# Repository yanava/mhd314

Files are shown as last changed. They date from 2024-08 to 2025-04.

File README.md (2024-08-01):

# Mahaudio MHD314 Audio DAC for the RaspberryPi

This is a hardware project for an open Hi-Fi DAC design for the RaspberryPi. MHD stands for Mahaudio Hi-Fi DAC and 314 is an obvious reference to the Pi. 

## Description

This is a project conducted through a series of YouTube live events, which can be accessed on the following playlist: https://www.youtube.com/watch?v=isWnR_Fm9iQ&list=PLo5SrSJMaUGJOzglfgmpuGIEasF4YtCA1&pp=iAQB - Portuguese language only for now. The purpose is educational, to show audio enthusiasts what is the necessary work to develop and integrate a product.

## Presentations

All presentations used on the live events are available under the Documentation folder. 

## License

This project is licensed under the BSD-3 License.

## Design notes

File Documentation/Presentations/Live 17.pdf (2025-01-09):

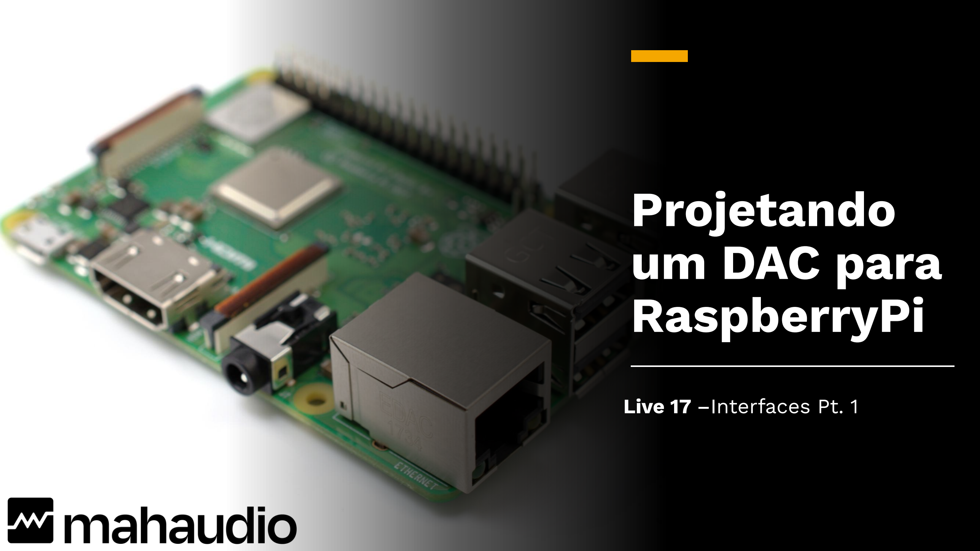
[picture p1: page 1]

# Projetando um DAC para RaspberryPi

## Live 17 –Interfaces Pt. 1

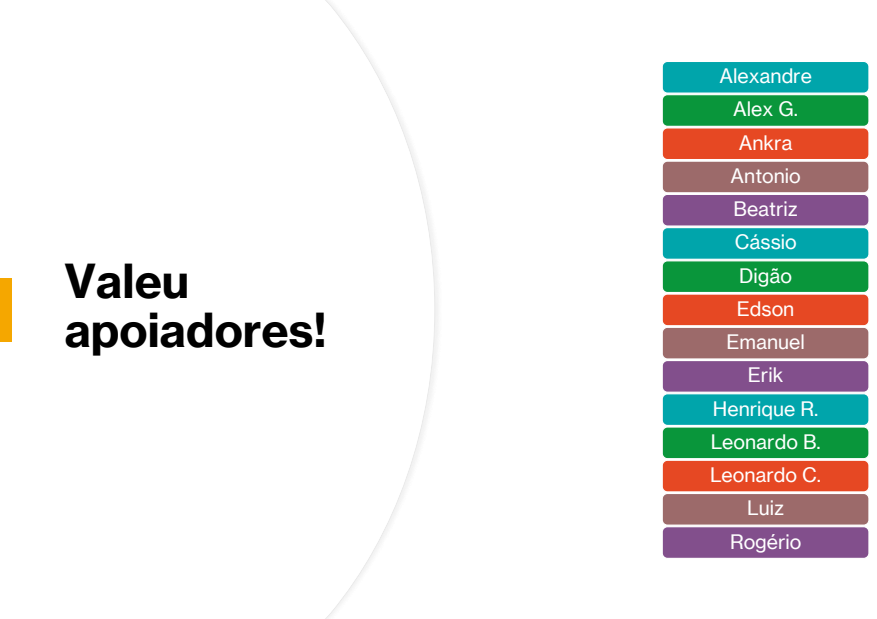
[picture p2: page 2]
Valeu apoiadores!; Alexandre; Alex G.; Ankra; Antonio; Beatriz; Cássio; Digão; Edson; Emanuel; Erik; Henrique R.; Leonardo B.; Leonardo C.; Luiz; Rogério

# Terminamos a fonte!

# Na última live

# Interfaces

## - Entrada – RaspberryPi

## - Saída – Conectores de Audio

## - Usuário – Controles e Indicadores

# Revendo nossa especificação

Item | Descrição | Requisito | Prioridade | Justificativa
1 | Tamanho | 65 x 56.5mm | Referência | Norma
2 | Entrada áudio | I2S – SCK, WS e SD | Obrigatório | Compatibilidade com RPi
3 | Saída SE - Conector | 3.5mm TRS | Obrigatório | Conectividade
4 | Saída DIFF - Conector | 4.4mm Pentaconn | Obrigatório | Conectividade
5 | Potência de Saída | 150mW RMS | Obrigatório | Fones target
6 | Entrada energia | 5V – 500mA 3.3V – 500mA | Referência | Compatibilidade com fontes de mercado p/ RPi

# Revendo nosso diagrama de blocos

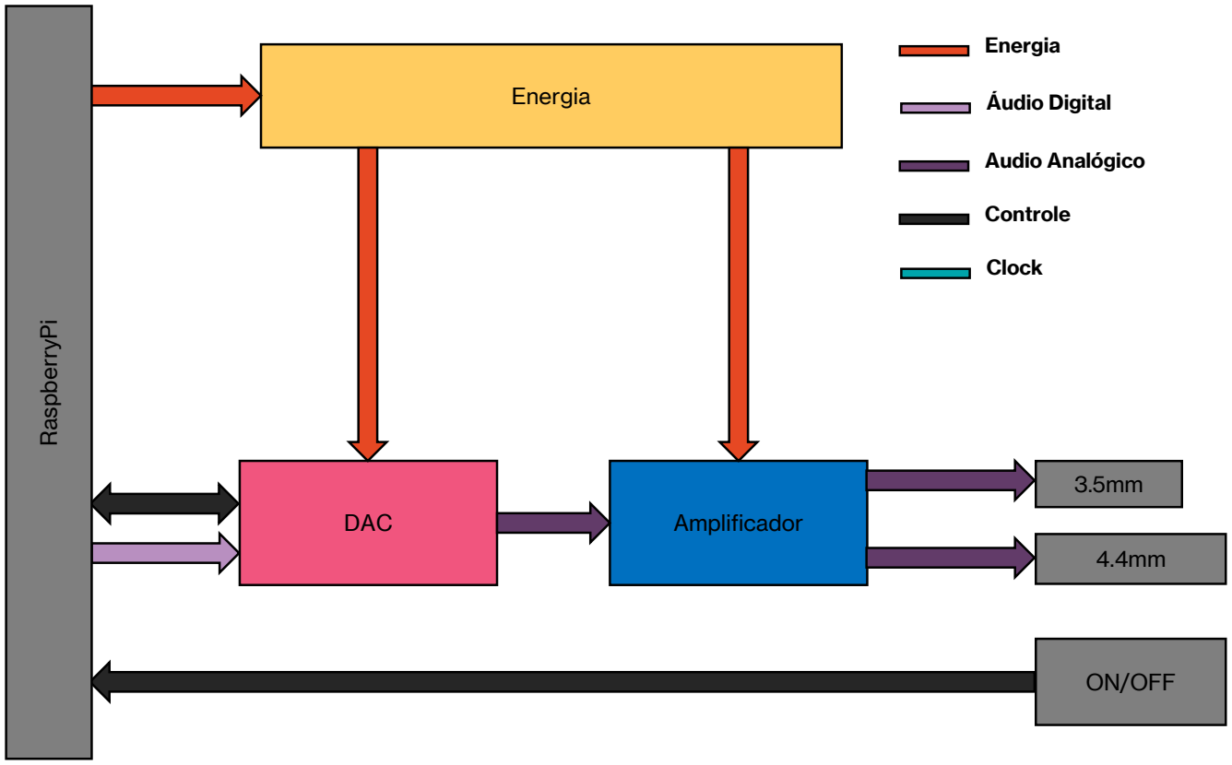
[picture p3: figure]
Energia; DAC; Amplificador; ON/OFF; RaspberryPi; Audio Analógico; Controle; Clock; Áudio Digital

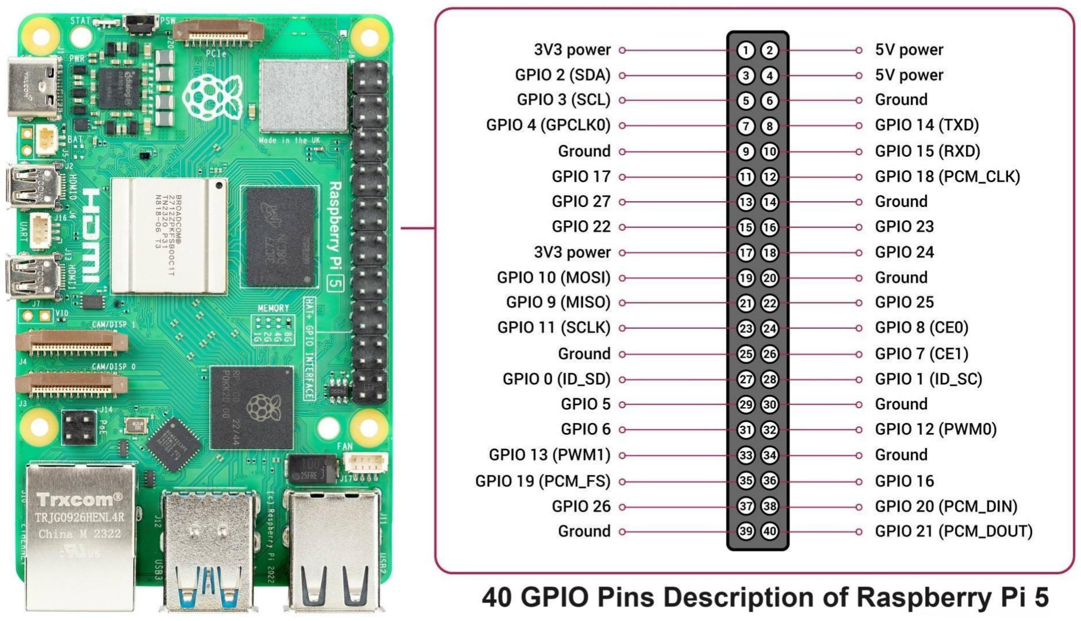
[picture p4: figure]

# Conector da RaspberryPi

# BCM Peripherals

## - Documento listando todos os periféricos do chip principal

## - Mostra distribuição dos periféricos em todos os pinos

## - Diferentes alocações são possíveis

## - Vamos fazer um tour do documento

# Pinos necessários

- Áudio – 3 Pinos
- 1 pino PCM_DATA
- 1 pino PCM_FS
- 1 pino PCM_CLK
- Controle – 8 Pinos
- 1 pino I2C_SCL
- 1 pino I2C_SDA
- 1 pino GPIO para Reset do ES9038Q2M
- 1 pino GPIO para Mute do OPA1622 Single Ended
- 1 pino GPIO para Mute do OPA1622 Diferencial
- 3 Pinos para LED
- Reconhecimento – 2 Pinos
- 1 pino ID_SD
- 1 pino ID_SC
- Alimentação – 10 Pinos
- 2 pinos de +5V
- 8 pinos GND (Terra)

# 23 de 40 Pinos

Alocando os pinos temos...

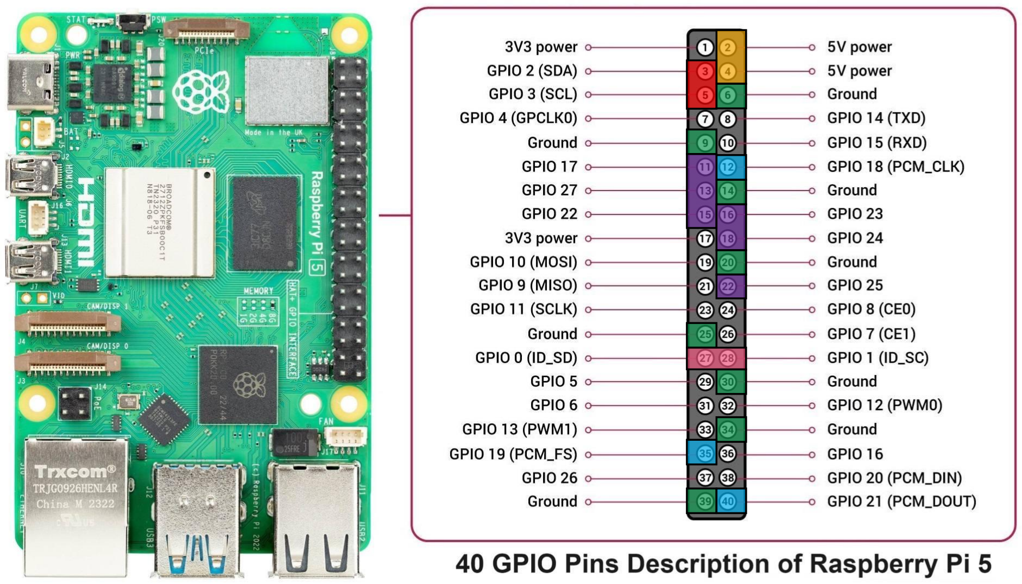
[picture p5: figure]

# Esquema de Identificação

## - Memória EEPROM na nossa placa

## - Identificação automática

## - Plug and play

## - Automaticamente carrega os drivers

## - Apenas 2 pinos

## - Documentação no Github da RPi

# Conectores de Áudio

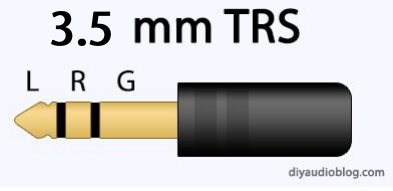
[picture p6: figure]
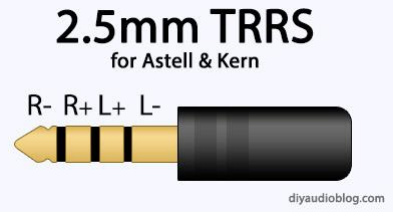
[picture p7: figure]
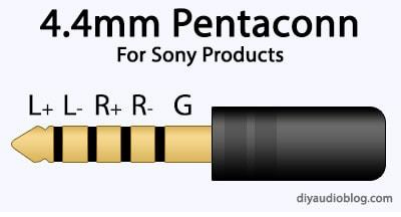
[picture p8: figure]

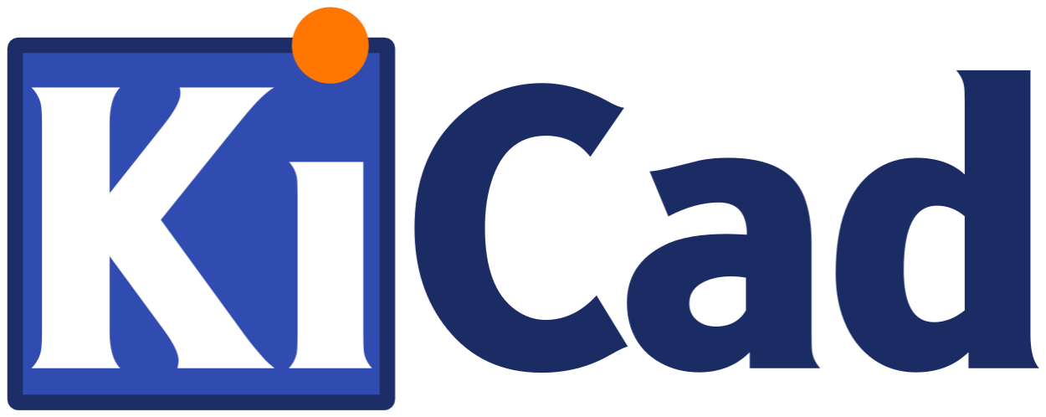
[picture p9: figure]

# Bora pro KiCad!

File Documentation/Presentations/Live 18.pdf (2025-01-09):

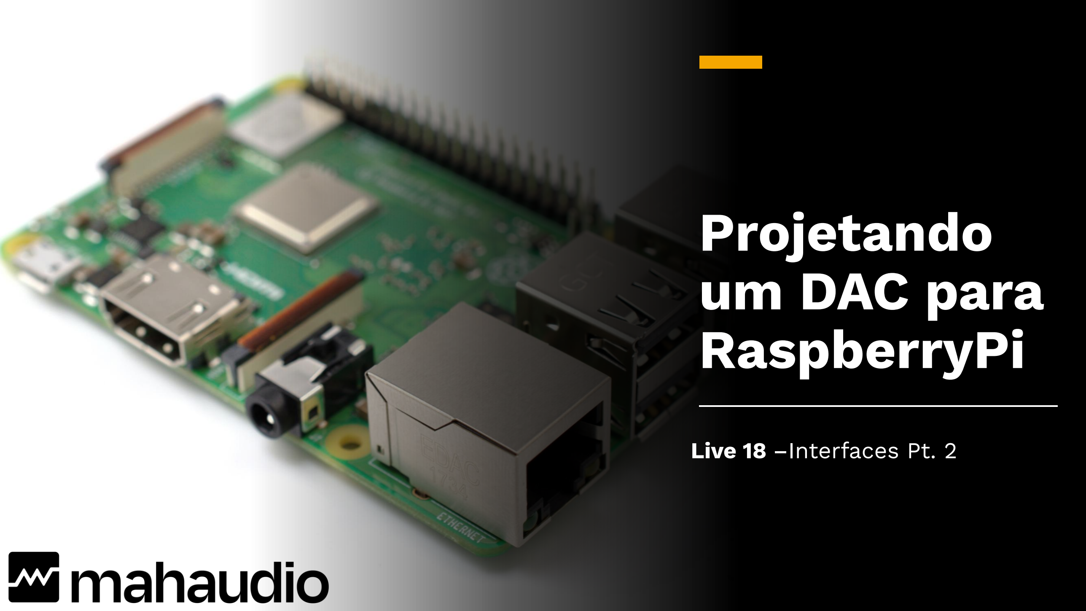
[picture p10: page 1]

# Projetando um DAC para RaspberryPi

### Live 18 –Interfaces Pt. 2

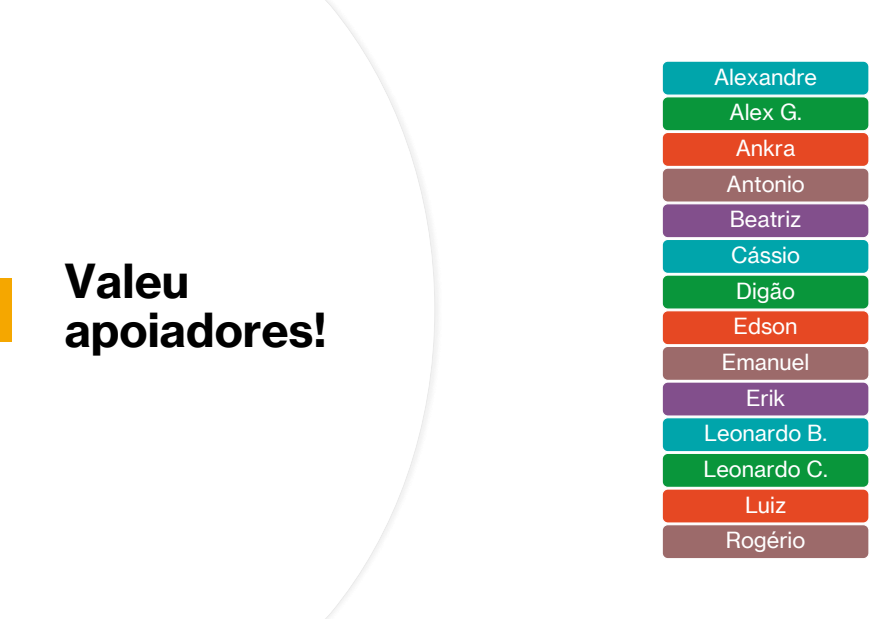
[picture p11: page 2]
Valeu apoiadores!; Alexandre; Alex G.; Ankra; Antonio; Beatriz; Cássio; Digão; Edson; Emanuel; Erik; Leonardo B.; Leonardo C.; Luiz; Rogério

# Na última live

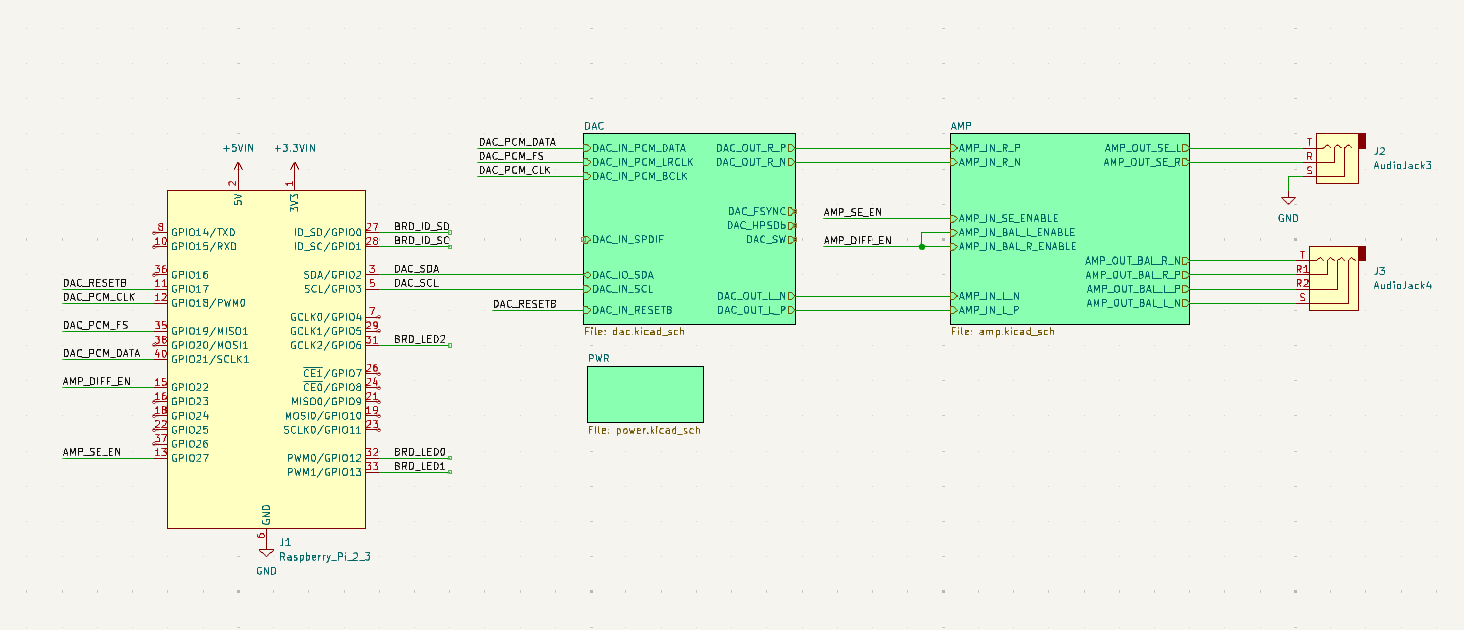
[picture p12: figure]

# Nesta live

### - Footprint dos conectores

### - LEDs

### - EEPROM

### - Testpoints


# Bora pro KiCad!

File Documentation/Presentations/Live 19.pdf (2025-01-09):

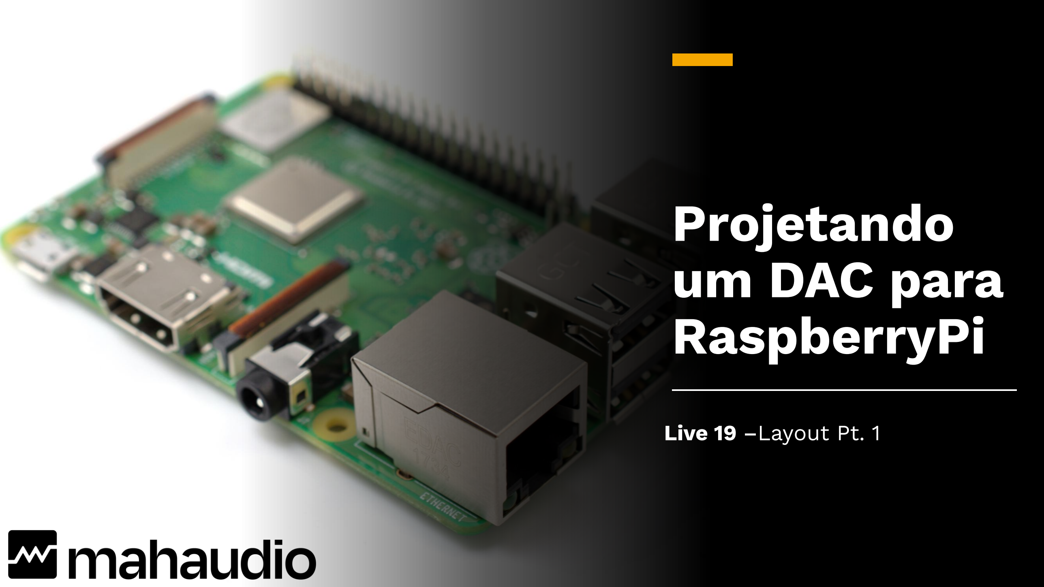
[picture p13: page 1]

# Projetando um DAC para RaspberryPi

### Live 19 –Layout Pt. 1

Valeu apoiadores!; Alexandre; Alex G.; Ankra; Antonio; Beatriz; Cássio; Digão; Edson; Emanuel; Erik; Leonardo B.; Leonardo C.; Luiz; Rogério

# Na última live

### - Fim do esquema elétrico!

# Nesta live

### - Tour do esquema

### - Passar tudo para a placa!


# Bora pro KiCad!

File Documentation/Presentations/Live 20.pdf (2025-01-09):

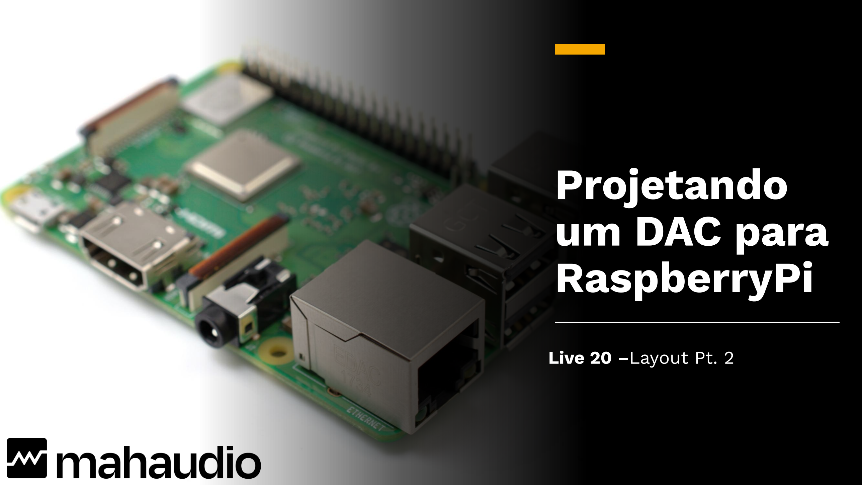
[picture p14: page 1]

# Projetando um DAC para RaspberryPi

### Live 20 –Layout Pt. 2

Valeu apoiadores!; Alexandre; Alex G.; Ankra; Antonio; Beatriz; Cássio; Digão; Edson; Emanuel; Erik; Leonardo B.; Leonardo C.; Luiz; Rogério

# Na última live

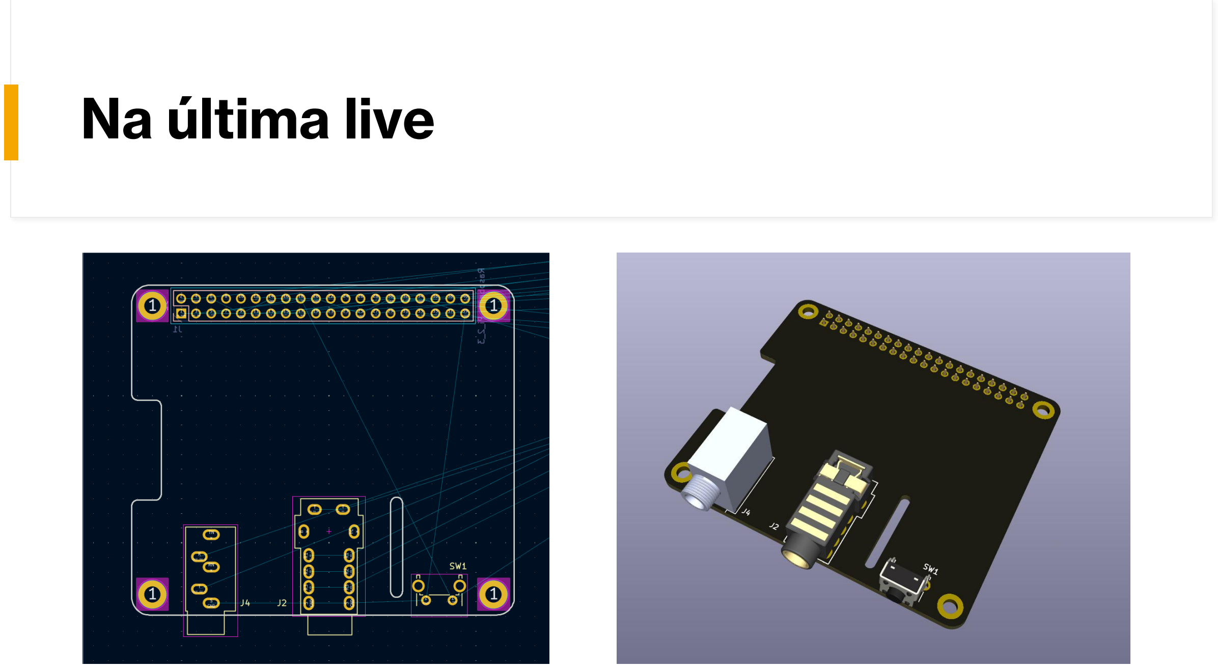
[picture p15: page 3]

# Nesta live - Placement

### - Conectores (OK!)

### - Fonte de alimentação

### - DAC

### - AMP


# Bora pro KiCad!

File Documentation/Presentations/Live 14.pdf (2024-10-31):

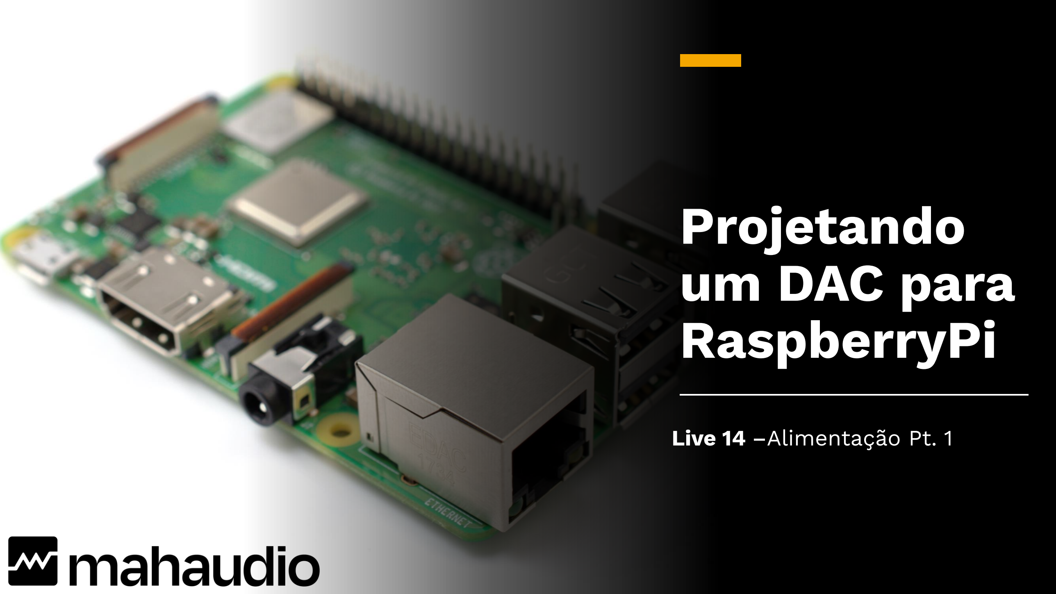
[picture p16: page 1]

# Projetando um DAC para RaspberryPi

Live 14 –Alimentação Pt. 1

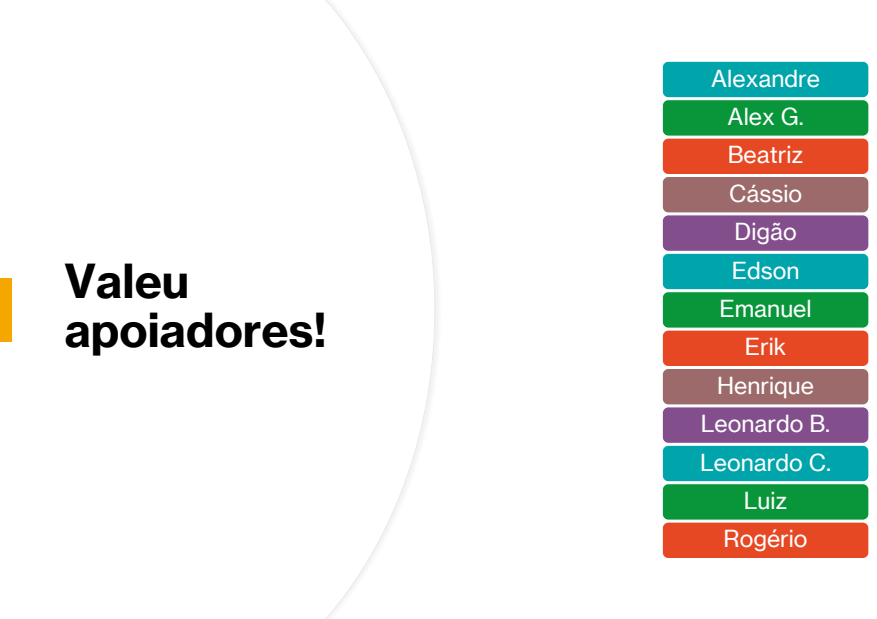
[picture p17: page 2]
Valeu apoiadores!; Alexandre; Alex G.; Beatriz; Cássio; Digão; Edson; Emanuel; Erik; Henrique; Leonardo B.; Leonardo C.; Luiz; Rogério

# Sorteios KZ ZS10 Pro 2 (Reloaded)

### - Aberto

- KZ ZS10 Pro 2 + Camiseta Amplificou Direito
- Regra: Comentário no LIVE de HOJE!
- Sorteio na próxima LIVE – a combinar
- Corte – (Data da live – 1) dia
- Todos apoiadores acima do nível Técnico já participam

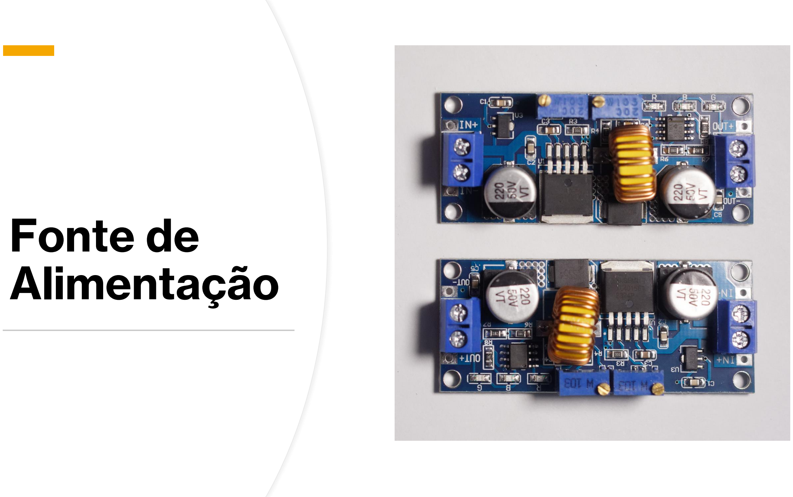
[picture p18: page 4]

# Fonte de Alimentação

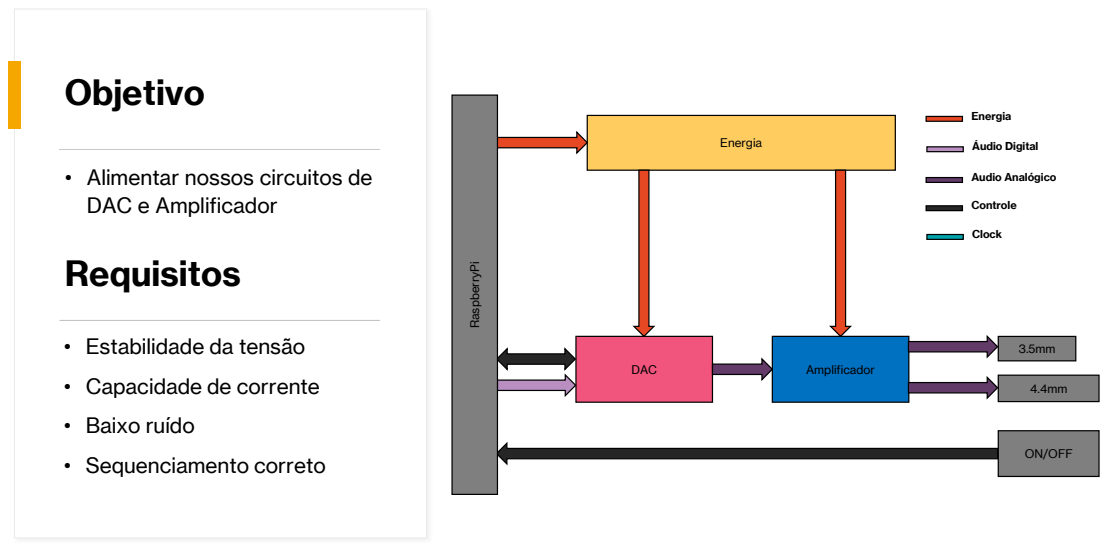
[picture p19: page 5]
DAC e Amplificador; Energia; DAC; Amplificador; ON/OFF; RaspberryPi; Audio Analógico; Controle; Clock; Áudio Digital; Requisitos

Objetivo • Alimentar nossos circuitos de

• Estabilidade da tensão • Capacidade de corrente • Baixo ruído • Sequenciamento correto

# Lembrando nossa spec

### - Tensões de entrada vindas da RaspberryPi (requisito)

Item | Descrição | Requisito | Prioridade | Justificativa
1 | Tamanho | 65 x 56.5mm | Referência | Norma
2 | Entrada áudio | I2S – SCK, WS e SD | Obrigatório | Compatibilidade com RPi
3 | Saída SE - Conector | 3.5mm TRS | Obrigatório | Conectividade
4 | Saída DIFF - Conector | 4.4mm Pentaconn | Obrigatório | Conectividade
5 | Potência de Saída | 150mW RMS | Obrigatório | Fones target
6 | Entrada energia | 5V – 500mA 3.3V – 500mA | Referência | Compatibilidade com fontes de mercado p/ RPi

# Reguladores de Tensão Lineares

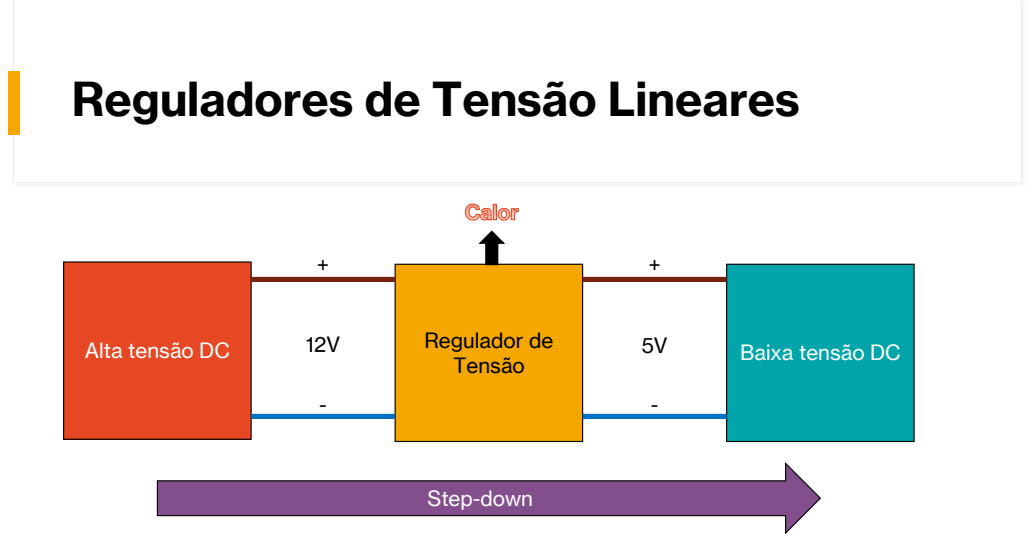
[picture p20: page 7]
Alta tensão DC; Baixa tensão DC Regulador de; Tensão; Step-down; Calor

# Reguladores Lineares

### - Vantagens

- Simples de projetar (+ poucos componentes)
- Baixo ruído
- Reação rápida a variações na carga

### - Desvantagens

- Eficiência menor (comparada a DC-DC)
- Apenas abaixam tensão
- Podem dissipar bastante calor

# Reguladores Chaveados (DC-DC)

Alta tensão DC | Baixa tensão DC Conversor
DC-DC

+

+

Step-down

Step-up

12V | 5V

# Reguladores DC-DC inversores (chaveados)

Alta tensão DC | Baixa tensão DC Conversor
DC-DC

+

+

Inverter

5V | -12V

# Reguladores Chaveados

### - Vantagens

- Alta eficiência
- Versatilidade
- Correntes de saída maiores

### - Desvantagens

- Mais complexos de projetar (+ componentes)
- Ruído de chaveamento
- Resposta a transiente

# Metodologia

### - Tomamos nota de todas as tensões que precisamos

### - Requisitos de corrente para cada tensão

### - Escolha de topologia

- Tensões exclusivamente analógicas → Reguladores lineares
- Tensões exclusivamente digitais → Reguladores chaveados
- Podemos usar reguladores chaveados para subir tensão e lineares para reduzir o ruído

### - Escolha dos componentes

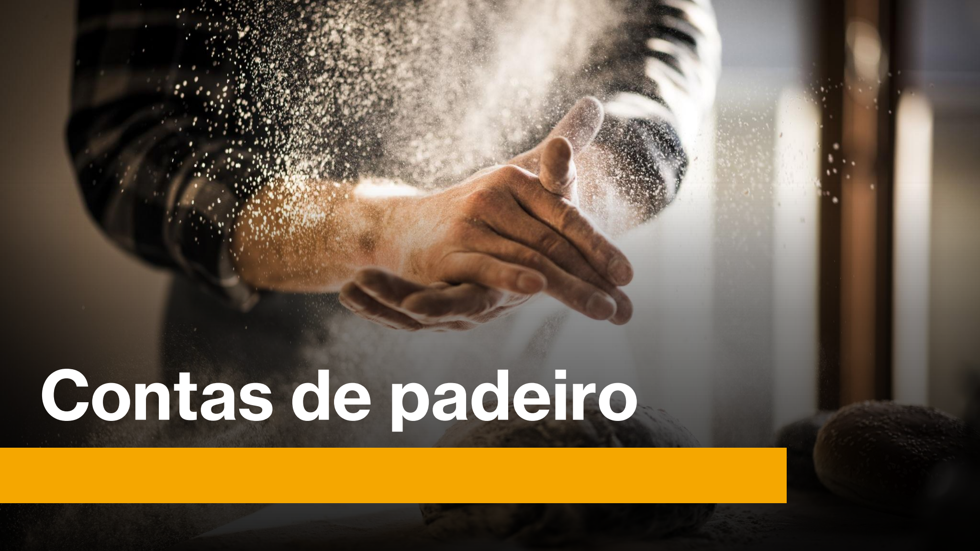
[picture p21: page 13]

# Contas de padeiro

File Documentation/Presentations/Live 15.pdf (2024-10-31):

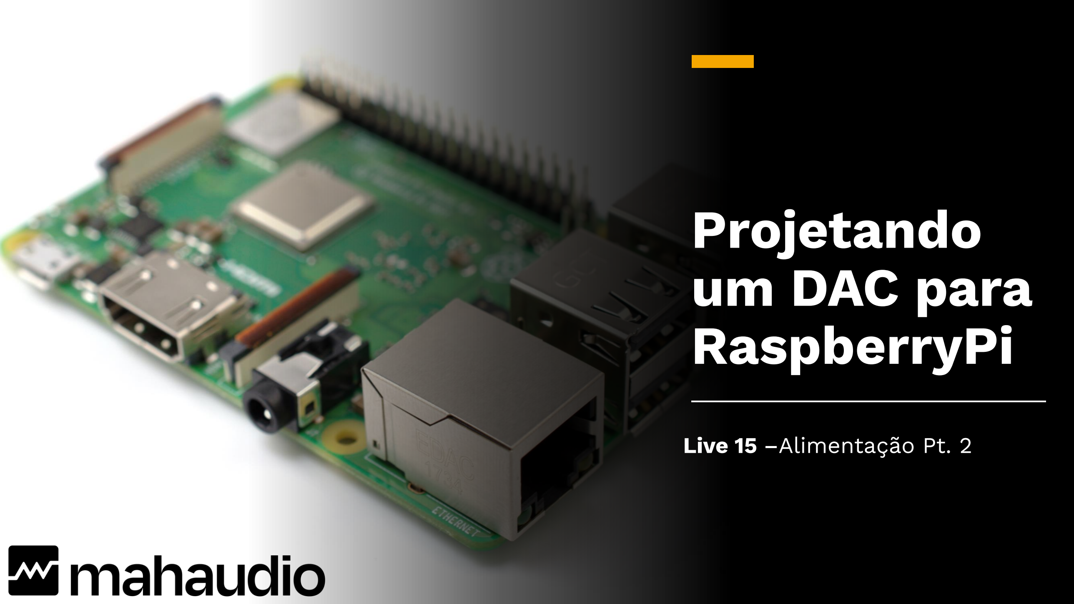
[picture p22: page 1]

# Projetando um DAC para RaspberryPi

## Live 15 –Alimentação Pt. 2

Valeu apoiadores!; Alexandre; Alex G.; Beatriz; Cássio; Digão; Edson; Emanuel; Erik; Henrique; Leonardo B.; Leonardo C.; Luiz; Rogério

# Sorteios KZ ZS10 Pro 2 (Reloaded)

## - Aberto

- KZ ZS10 Pro 2 + Camiseta Amplificou Direito
- Regra: Comentário no LIVE de HOJE!
- Sorteio na próxima LIVE – a combinar
- Corte – (Data da live – 1) dia
- Todos apoiadores acima do nível Técnico já participam

# Na última live

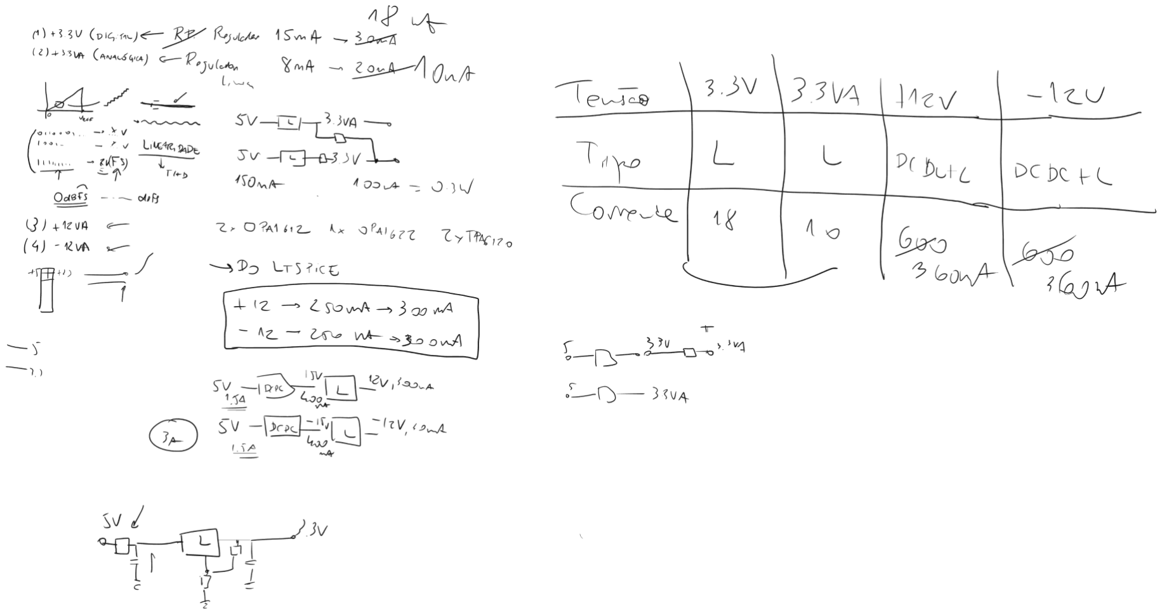
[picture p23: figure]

# Passando a limpo

Nome | Tensão | Corrente Requerida | Tipo de conversor
+3.3V | +3.3V | 20mA | Linear
+3.3VA | +3.3V | 10mA | Linear
+12VA | +12V | 350mA (RMSx2) | Chaveado → Linear
-12VA | -12V | 350mA (RMSx2) | Chaveado → Linear

# O problema dos 12V

# O problema dos 12V

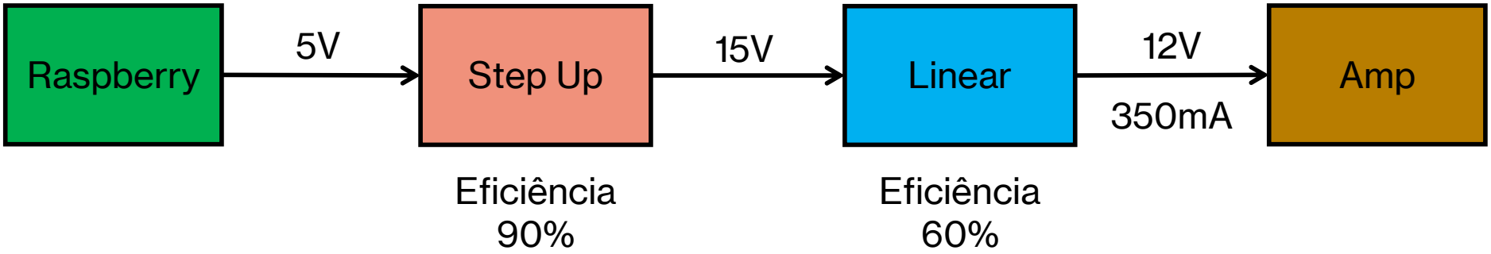
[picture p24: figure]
Step Up; Linear; Raspberry; Amp; Eficiência 60%; Eficiência 90%

# O problema dos 12V

Step Up; Linear; Raspberry; Amp; Eficiência 60%; Eficiência

# O problema dos 12V

Step Up; Linear; Raspberry; Amp; Eficiência 60%; Eficiência

# O problema dos 12V

Step Up; Linear; Raspberry; Amp; Eficiência 60%; Eficiência

# O problema dos 12V

Step Up; Linear; Raspberry; Amp; Eficiência 60%; Eficiência

# E quanto vai pros fones? (por lado)


## - Estamos consumindo quase 5W

## - E entregando 300mW

- 100mW Single Ended
- 200mW Diferencial
- Os valores de pico são muito maiores,

## mas também retem esse contraste

## - Péssima eficiência

- 0.3W / 5W = 6%

# Por que isto aconteceu?

## - Baixa excursão de sinal na saída

- Apenas 2~3Vrms
- Alimentação alta → Tensão alta no fone

## - Limite de corrente do OPA1622 (SE)

## - Margem para aumento no TPA6120 (BAL)

- Grandes diferenças entre Balanceado e Single-Ended

# Entendendo o compromisso

Impedância

V = Z * I


Baixa Impedância | Alta Impedância
- Exige Corrente • Limitado pelo AMP • Tensão RMS baixa • Corrente RMS alta | • Exige Tensão • Limitado pela fonte • Tensão RMS alta • Corrente RMS baixa

# Impedância não está sozinha

Impedância

Sensibilidade

# Impedância não está sozinha


Impedância

Sensibilidade

Fáceis
(IEMs)

TinHiFi T2

# Impedância não está sozinha

Impedância

Sensibilidade

Fáceis
(Over)


Sennheiser HD600

# Impedância não está sozinha


Impedância

Sensibilidade

Médios
(Over)

Beyerdynamic
DT 990 PRO 250 Ohm

# Impedância não está sozinha


Impedância

Sensibilidade

Difíceis
(Over)

Hifiman HE400SE

# Impedância não está sozinha

Impedância

Sensibilidade

Fáceis (IEMs) | Fáceis (Over)
Difíceis (Over) | Médios (Over)

# Onde priorizar?

## - Baixa impedância

- Corrente de saída garantida
- Tensão insuficiente para fones de alta impedância

## - Alta impedância

- Tensão alta
- Amplificadores saturarão em baixas impedâncias


# O que fazer?

# Abaixar o ego e focar no bom senso

### - Preservar excursão baixa - OPA1622 em SE e BAL - Trocar as fontes para +/- 5V

- Tirar tudo que a fonte tiver para dar

### - Escalonar ganho e potência

- Reduzir dissipação na fonte e amplificador

### - Equalizar experiência entre Single Ended e Balanceado - Priorizar baixas impedâncias

- Maior parte dos fones com baixa sensibilidade são de baixa impedância


# Circuito Revisado


# Circuito

# Resultado da simulação (por lado)


## - Passamos a consumir 1.5W

## - E entregando 330mW

- 160mW Single Ended
- 170mW Diferencial

## - Eficiência evoluiu para

- 0.33W / 1.5W = 22%
- 260% de aumento

# E a potência consumida da Raspberry?

Step Up; Linear; Raspberry; Amp; Eficiência 60%; Eficiência

# Próximos passos

## - Ajustar o amp

## - Desenhar um diagrama de blocos pra fonte

## - Buscar reguladores lineares e chaveados

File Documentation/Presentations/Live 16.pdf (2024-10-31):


# Projetando um DAC para RaspberryPi

## Live 16 –Alimentação Pt. 3

Valeu apoiadores!; Alexandre; Alex G.; Ankra; Antonio; Beatriz; Cássio; Digão; Edson; Emanuel; Erik; Henrique R.; Leonardo B.; Leonardo C.; Luiz; Rogério

# Baixamos a bola!

# Na última live

# Projeto TPS65131


Parâmetros
- VIN = 5V
- VPOS = 8V
- IPOS = 604mA (pk) ; 352mA (rms)
- VNEG = -8V
- INEG = 625mA (pk) ; 377mA (rms)

Características TPS65131
- VREF = 1.213V
- fosc = 1.38MHz

# Tensão de Saída

Para VPOS:; Vpos; Vref; Escolhemos R1 e calculamos R2; VPOS(real) = 8.03V
Para VNEG:; Vneg; Vref; Escolhemos R3 e calculamos R4; VNEG(real) = -8.08V

# Indutor – Corrente de Pico

Para corrente positiva:; ILP =; Vpos Vin ∗ 0.64; ∗ Ipos; Para corrente negativa:; ILN =; Vin − Vneg Vin ∗ 0.64; ∗ Ineg

Estas correntes precisam ser menores que as correntes máximas dos indutores

# Indutor – Indutância

Para fonte positiva:; Vin ∗(Vpos−Vin); ∆ILP∗fosc∗Vpos ∆ILP=20% ILP; 0.2∗1.51∗1.38MHz∗5; Para fonte negativa:; Vin ∗ Vneg; ∆ILN ∗ fosc ∗ (Vneg−Vin ) ∆ILN=20% ILN; 5 ∗ (−8) 0.2 ∗ 2.54 ∗ 1.38MHz ∗ (−8 − 5)

# Capacitor

Para fonte positiva:; min =; Ipos; ∗ (Vpos − Vin); fosc ∗ ∆Vpos ∗ Vpos ∆Vpos=10mV; 0.604 ∗ (8 − 5) 1.38MHz ∗ 0.01 ∗ 8; Para fonte negativa:; Ineg; ∗ Vneg; fosc ∗ ∆Vneg ∗ (Vneg−Vin) ∆Vneg=10mV; 0.625 ∗ (−8) 1.38MHz ∗ 0.01 ∗ (−8 − 5)

# Calculo do ripple (resumido)

Para fonte positiva:; ∆Vpos total = ∆Vpos + ∆VESRpos = 14.1mV; Para fonte negativa:; ∆Vneg total = ∆Vneg + ∆VESRneg = 13.2mV

# Diodo Retificador

## - Schottky → Baixas perdas

## - Corrente acima do pico

## - Candidatos

- 1N5819HW-7-F
- MBR130T1G
- MBR260HW
- MBRX120LF-TP
- MBR120LSFT3G

# PMOS para dsesacoplar da saída

Evitar condução neste caminho


### - VTH << 5V

- VGSMAX > 5V

### - ID > ITOTAL =0.604 + 0.625 = 1.23A

### - Candidatos

- AO3419
- AD3409
- DMG23011
- FDN340P

### - Resistor de curto circuito

# Estabilização loop de controle (opcional)

Para fonte positiva:

C9 =

6.8μ
R1

= 6.8pF

Para fonte negativa:

C9 =

7.5μ
R1

= 7.5pF

# Projeto LM317/337


- R1 e R2 ajustam VO
- CADJ e D2 só são usados para fontes ajustáveis
- CI é importante para
desacoplamento
- CO melhora resposta a transiente
- D1 é recomendado para que CO não descarregue no regulador
- Fonte negativa tem mesmos calculos

Tensão de Saída +5VA; Vo = Vref 1 +; + IadjR2; Sabendo que:; • VO = 5V • VREF = 1.25V • IADJ = 50uA; (Vo−Vref) ∗ R1; Vref + IadjR1

Fazemos R1 = 240Ω (referência, datasheet)

Tensão de Saida -5VA; −Vo = −Vref 1 +; − IadjR2; Sabendo que:; • VO = 5V • VREF = 1.25V • IADJ = 50uA; (Vo−Vref) ∗ R1; Vref + IadjR1

Fazemos R1 = 240Ω (referência, datasheet)

Tensão de Saída +3.3V e +3.3VA; Vo = Vref 1 +; + IadjR2; Sabendo que:; • VO = 3.3V • VREF = 1.25V • IADJ = 50uA; (Vo−Vref) ∗ R1; Vref + IadjR1

Fazemos R1 = 240Ω (referência, datasheet)

# Demais componentes

## - Capacitores

- Vamos usar os valores de referência
- Um de 100nF e um de 1uF

## - Não usaremos diodo de descarga


# Bora pro KiCad!

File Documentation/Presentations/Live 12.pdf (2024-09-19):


# Projetando um DAC para RaspberryPi

Live 12 – Amplificador Pt. 3

Valeu apoiadores!; Alexandre; Alex G.; Beatriz; Cássio; Digão; Edson; Emanuel; Erik; Henrique; Leonardo B.; Leonardo C.; Luiz; Rogério


# Medidas no ar!

Acesse:
mahaudio.com.br/medicoes

# Na live passada…


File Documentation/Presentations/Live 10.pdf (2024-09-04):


# Projetando um DAC para RaspberryPi

## Live 10 – Amplificador Pt. 1

### Alexandre

Alex G.

Valeu apoiadores!; Beatriz; Cássio; Digão; Edson; Emanuel; Erik; Henrique; Leonardo B.; Leonardo C.; Luiz; Rogério


# Na live passada…

# Lembrando nossa spec

Item | Descrição | Requisito | Prioridade | Justificativa
1 | Tamanho | 65 x 56.5mm | Referência | Norma
2 | Entrada áudio | I2S – SCK, WS e SD | Obrigatório | Compatibilidade com RPi
3 | Saída SE - Conector | 3.5mm TRS | Obrigatório | Conectividade
4 | Saída DIFF - Conector | 4.4mm Pentaconn | Obrigatório | Conectividade
5 | Potência de Saída | 150mW RMS | Obrigatório | Fones target
6 | Entrada energia | 5V – 500mA 3.3V – 500mA | Referência | Compatibilidade com fontes de mercado p/ RPi

# Lembrando nossa spec

| Sennheiser HD600 | Hifiman HE400SE
Z | 322Ω | 25.3Ω
Lp | 110dBSPL
S | 100.5dB/mW | 88.7dB/mW
P | 8.91mW | 134.90mW
VRMS | 1.69V | 1.84V
IRMS | 5.27mA | 73.32mA

# Estágio de Saída de um DAC

LP

DAC; Conversor I/V; Filtro LP; Opcionais (conversores, pop eliminator, volume, etc); Conector

RP

# TI App Note

Simulação LTSpice; • Ver o sinal de saída • Compreender a dinâmica do circuito; Simulação transiente; • Entender o comportamento em frequencia (filtros); Simulação AC

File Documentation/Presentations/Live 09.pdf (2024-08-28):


# Projetando um DAC para RaspberryPi

## Live 09 – Esquema elétrico Pt. 2

# Valeu apoiadores!


- Alexandre
- Alex G.
- Beatriz
- Cássio
- Digão
- Edson
- Erik
- Henrique
- Leonardo B.
- Leonardo C.
- Luiz
- Rogério


# Esquema elétrico com ES9038Q2M

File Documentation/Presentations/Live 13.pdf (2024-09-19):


# Projetando um DAC para RaspberryPi

Live 13 – Amplificador Pt. 4

Valeu apoiadores!; Alexandre; Alex G.; Beatriz; Cássio; Digão; Edson; Emanuel; Erik; Henrique; Leonardo B.; Leonardo C.; Luiz; Rogério


# Aniversário de 1 ano do canal!

# Sorteios!

### - Aberto

- Truthear Gate + Camiseta Amplificou Direito
- Regra: Inscrito no Canal + Comentário no LIVE de HOJE!
- Sorteio na próxima LIVE, dia 25/09
- Corte – 24/09

### - Apenas apoiadores

- KZ ZS10 Pro 2 + Camiseta Amplificou Direito
- Sorteio na próxima LIVE, dia 25/09
- Todos os apoiadores estão participando automaticamente


# Na live passada…


# Veremos a luz?

# TPA6120A2


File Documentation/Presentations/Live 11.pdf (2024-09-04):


# Projetando um DAC para RaspberryPi

Live 11 – Amplificador Pt. 2

Valeu apoiadores!; Alexandre; Alex G.; Beatriz; Cássio; Digão; Edson; Emanuel; Erik; Henrique; Leonardo B.; Leonardo C.; Luiz; Rogério


# Na live passada…

Alguns pontos esquecidos; Corrente de offset; Falta de um estágio de saída com capacidade de corrente

# Revisitanto a App Note da TI


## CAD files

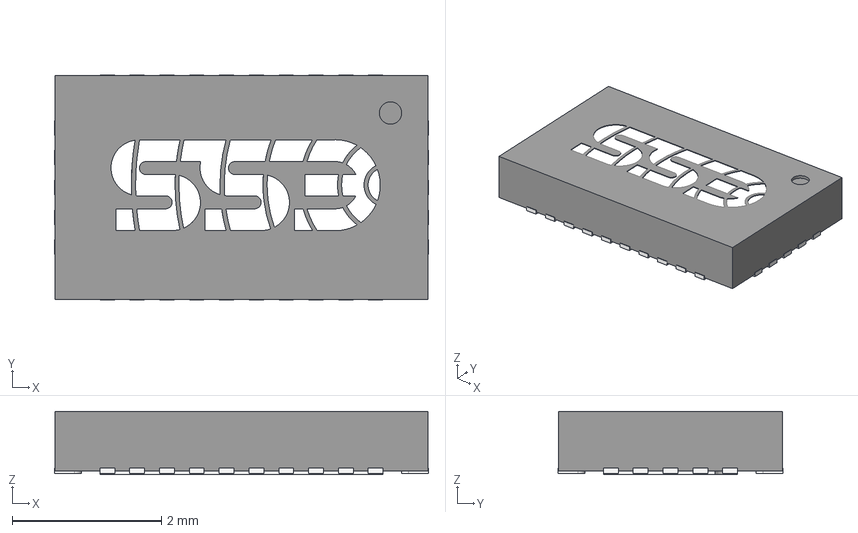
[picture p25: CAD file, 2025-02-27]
Bundled 3D/es9038.step
5.02 x 3.02 x 0.85 mm

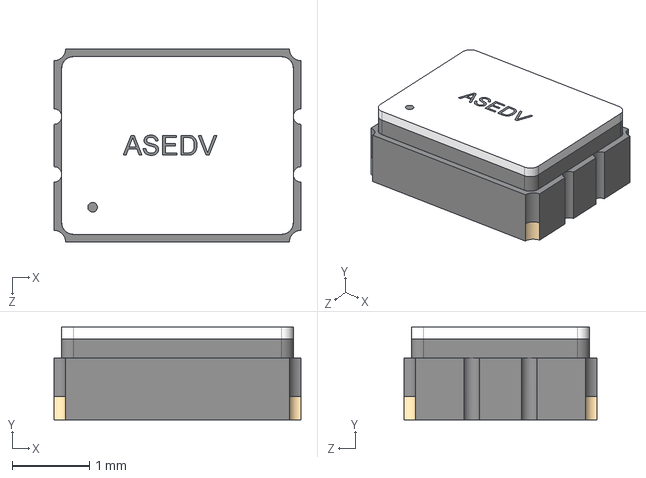
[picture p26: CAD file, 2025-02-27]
Bundled 3D/ASE-50.000MHZ-LC-T.STEP
3.20 x 1.20 x 2.50 mm

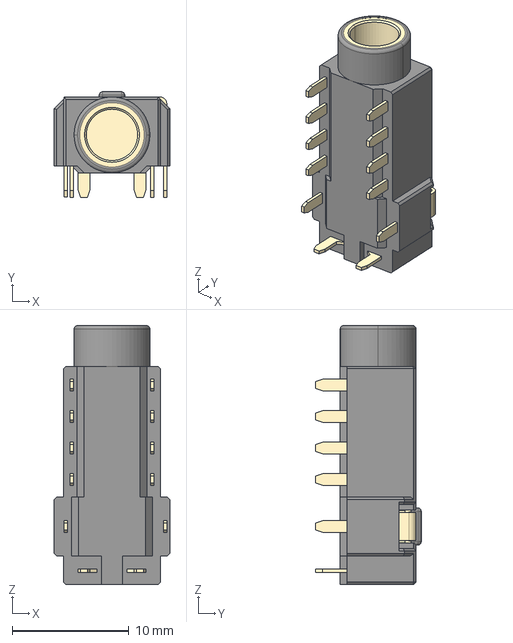
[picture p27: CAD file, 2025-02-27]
Bundled 3D/nba1-24-001.step
9.90 x 9.05 x 22.2 mm

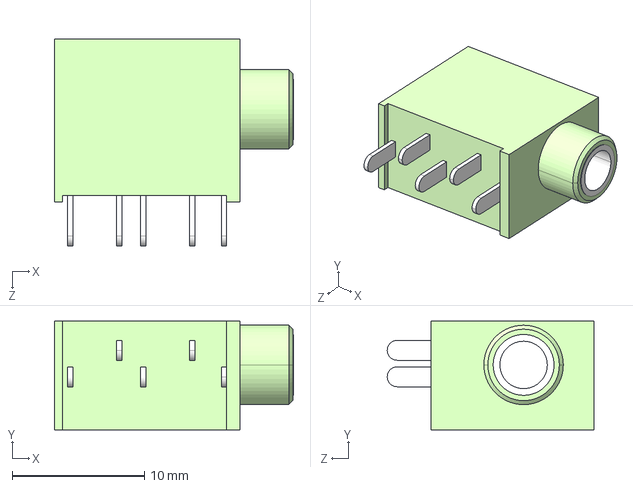
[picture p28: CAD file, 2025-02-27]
Bundled 3D/SJ1-3535NG-GR.step
18.1 x 8.20 x 15.6 mm

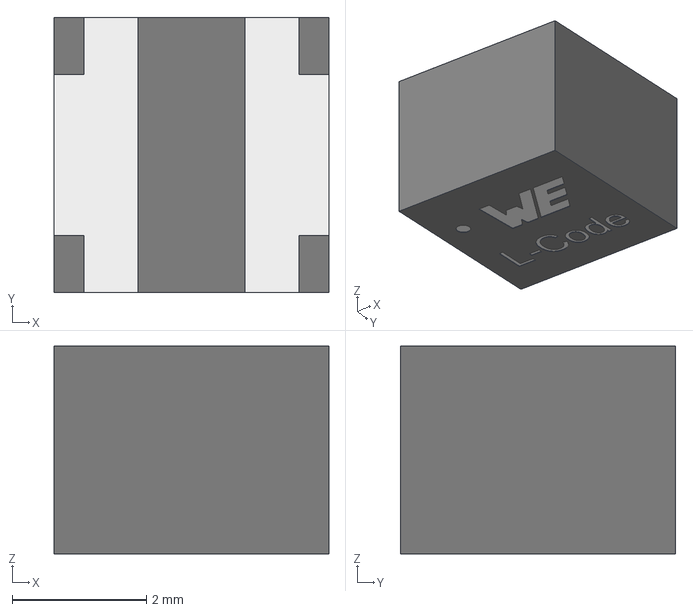
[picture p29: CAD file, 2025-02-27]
Bundled 3D/WE-MAPI_4030.step
4.10 x 4.10 x 3.10 mm
body_SSMC_4030
land_pattern_SSMC_4020 x 2

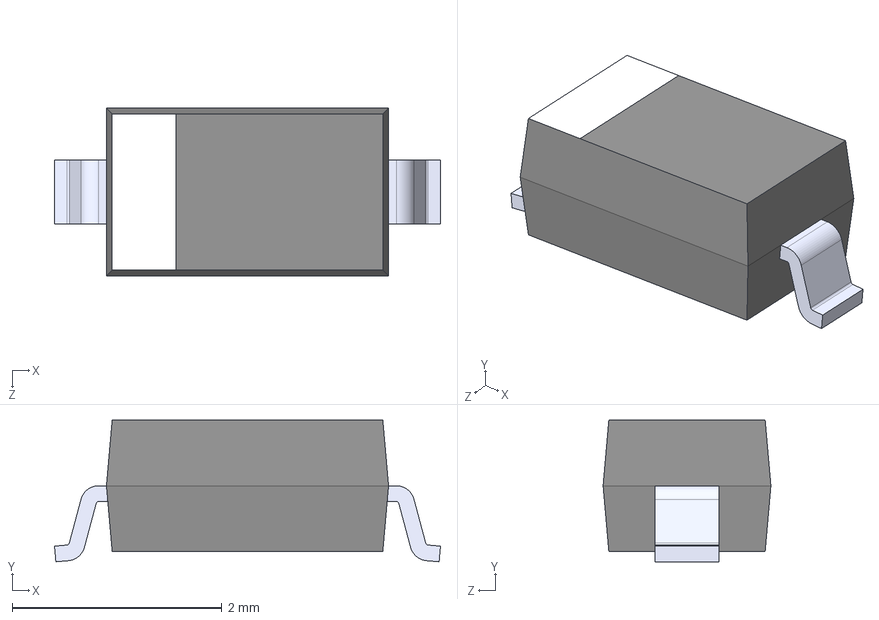
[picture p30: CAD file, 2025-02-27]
Bundled 3D/MBR130T1G.step
3.68 x 1.35 x 1.60 mm

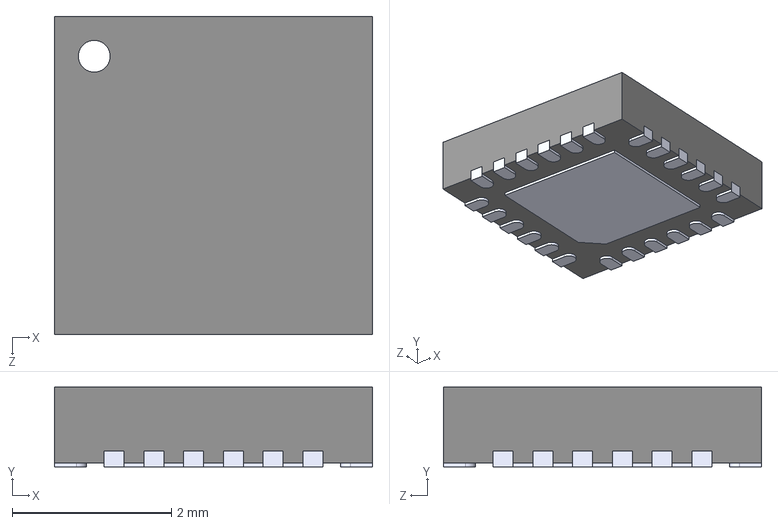
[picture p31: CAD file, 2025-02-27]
Bundled 3D/TPS65130RGER--3DModel-STEP-56544.STEP
4.00 x 1.00 x 4.00 mm

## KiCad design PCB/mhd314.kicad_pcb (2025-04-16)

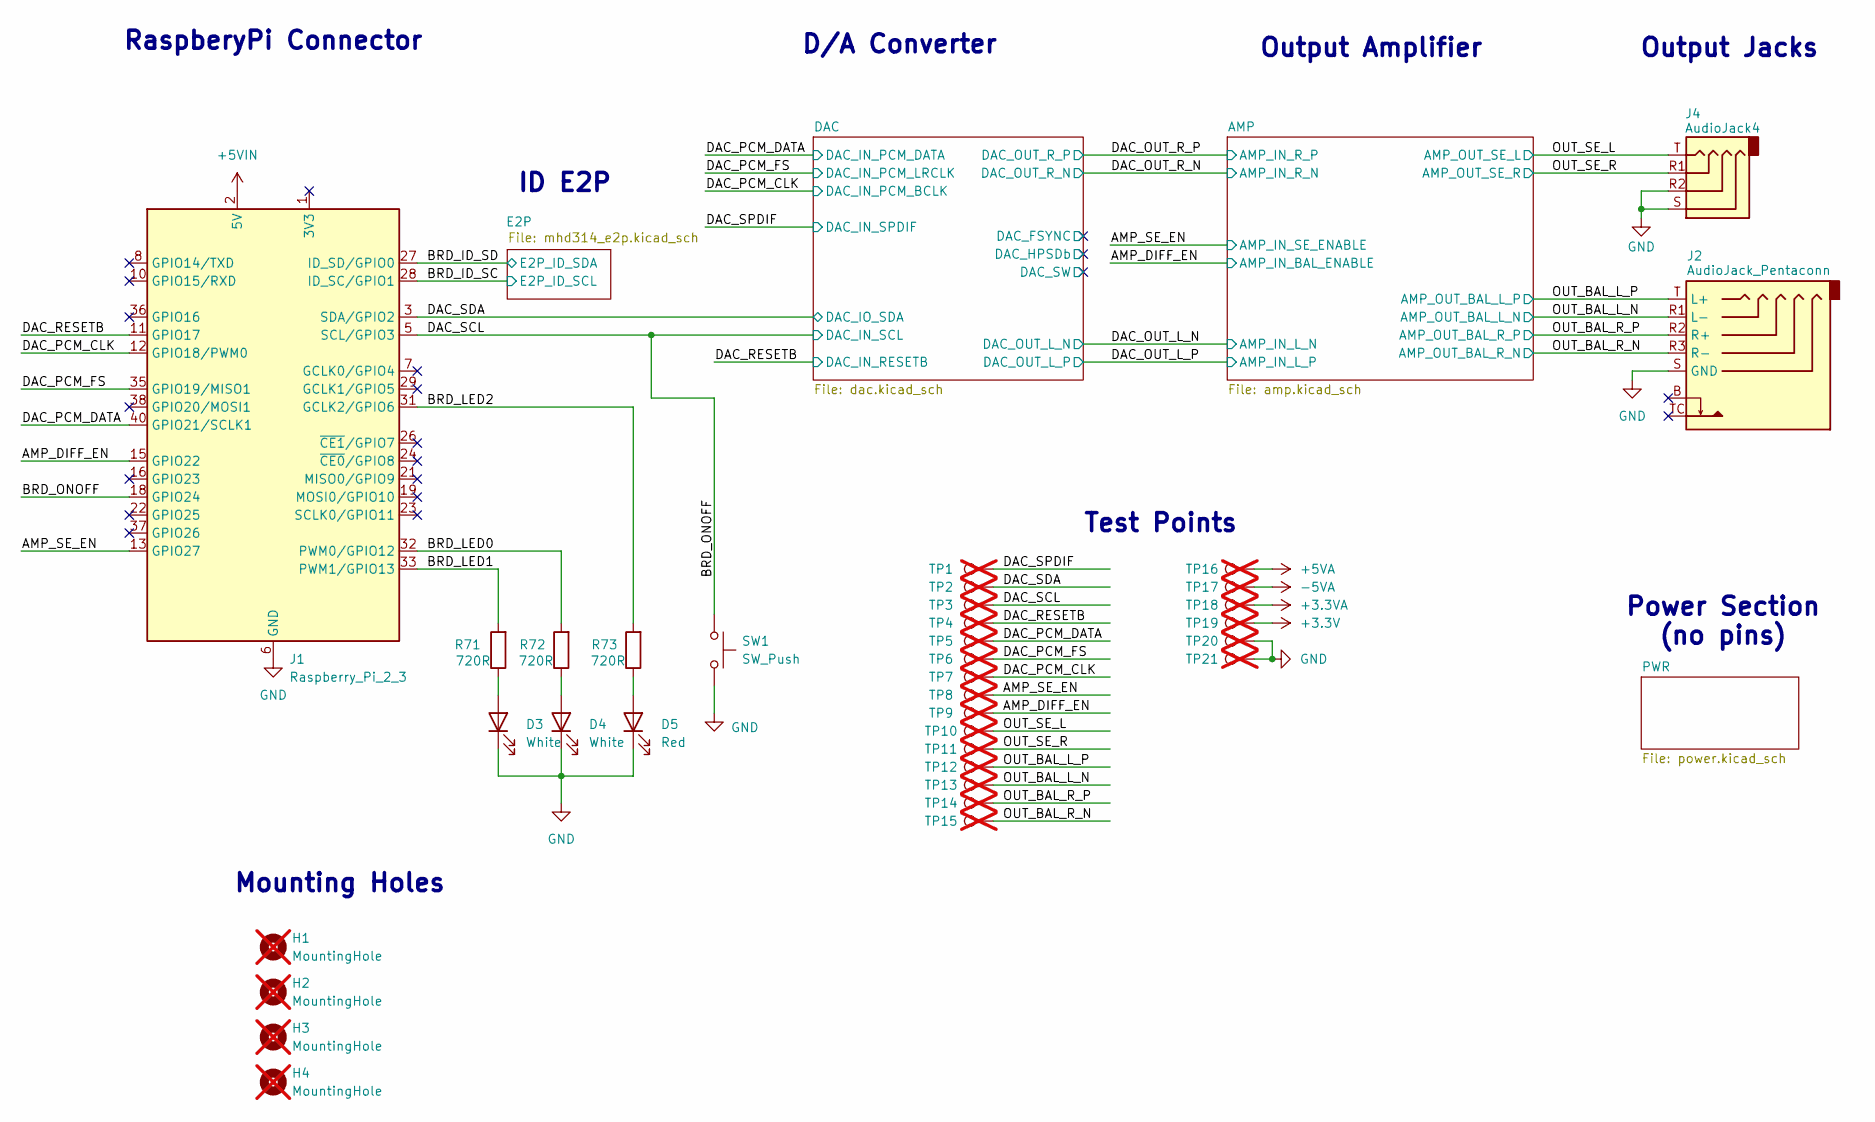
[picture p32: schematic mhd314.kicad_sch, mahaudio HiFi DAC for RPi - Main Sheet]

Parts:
D3, D4: White; LED_0603_1608Metric_Pad1.05x0.95mm_HandSolder; JLCPCB Part # C2290
D5: Red; LED_0603_1608Metric_Pad1.05x0.95mm_HandSolder; JLCPCB Part # C2286
H1, H2, H3, H4: MountingHole; MountingHole_2.7mm_M2.5_DIN965_Pad; not fitted
J1: Raspberry_Pi_2_3; PinSocket_2x20_P2.54mm_Vertical; JLCPCB Part # C132132
J2: AudioJack_Pentaconn; Jack_4.4mm_G-Switch_GT-3321667P-01_Horizontal; JLCPCB Part # C2762984
J4: AudioJack4; TENSILITY_54-00176; JLCPCB Part # C19857277
R71, R72, R73: 720R; R_0402_1005Metric_Pad0.72x0.64mm_HandSolder; Tolerance 1%; JLCPCB Part # C416571
SW1: SW_Push; SW_Tactile_SPST_Angled_PTS645Vx39-2LFS; JLCPCB Part # C285519
TP1, TP2, TP3, TP4, TP5, TP6, TP7, TP8, TP9, TP10, TP11, TP12, TP13, TP14, TP15, TP16, TP17, TP18, TP19, TP20, TP21: TestPoint; TestPoint_Pad_D1.0mm; not fitted

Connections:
+3.3V: TP19.1; also elsewhere on the board
+3.3VA: TP18.1; also elsewhere on the board
+5VA: TP16.1; also elsewhere on the board
+5VIN: J1.2 (5V), J1.4 (5V); also elsewhere on the board
-5VA: TP17.1; also elsewhere on the board
/AMP_DIFF_EN: J1.15 (GPIO22), TP9.1; also elsewhere on the board
/AMP_SE_EN: J1.13 (GPIO27), TP8.1; also elsewhere on the board
/BRD_ID_SC: J1.28 (ID_SC/GPIO1); also elsewhere on the board
/BRD_ID_SD: J1.27 (ID_SD/GPIO0); also elsewhere on the board
/BRD_LED0: J1.32 (PWM0/GPIO12), R72.2
/BRD_LED1: J1.33 (PWM1/GPIO13), R71.2
/BRD_LED2: J1.31 (GCLK2/GPIO6), R73.2
/BRD_ONOFF: J1.5 (SCL/GPIO3), J1.18 (GPIO24), SW1.1, TP3.1; also elsewhere on the board
/DAC_PCM_CLK: J1.12 (GPIO18/PWM0), TP7.1; also elsewhere on the board
/DAC_PCM_DATA: J1.40 (GPIO21/SCLK1), TP5.1; also elsewhere on the board
/DAC_PCM_FS: J1.35 (GPIO19/MISO1), TP6.1; also elsewhere on the board
/DAC_RESETB: J1.11 (GPIO17), TP4.1; also elsewhere on the board
/DAC_SDA: J1.3 (SDA/GPIO2), TP2.1; also elsewhere on the board
/DAC_SPDIF: TP1.1; also elsewhere on the board
/OUT_BAL_L_N: J2.R1 (L-), TP13.1; also elsewhere on the board
/OUT_BAL_L_P: J2.T (L+), TP12.1; also elsewhere on the board
/OUT_BAL_R_N: J2.R3 (R-), TP15.1; also elsewhere on the board
/OUT_BAL_R_P: J2.R2 (R+), TP14.1; also elsewhere on the board
/OUT_SE_L: J4.T, TP10.1; also elsewhere on the board
/OUT_SE_R: J4.R1, TP11.1; also elsewhere on the board
GND: D3.1 (K), D4.1 (K), D5.1 (K), J1.6 (GND), J1.9 (GND), J1.14 (GND), J1.20 (GND), J1.25 (GND), J1.30 (GND), J1.34 (GND), J1.39 (GND), J2.S (GND), J4.R2, J4.S, SW1.2, TP20.1, TP21.1; also elsewhere on the board
unnamed: D3.2 (A), R71.1
unnamed: D4.2 (A), R72.1
unnamed: D5.2 (A), R73.1

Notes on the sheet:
Test Points
Mounting Holes
Output Amplifier
ID E2P
Output Jacks
Power Section (no pins)
D/A Converter
RaspberyPi Connector

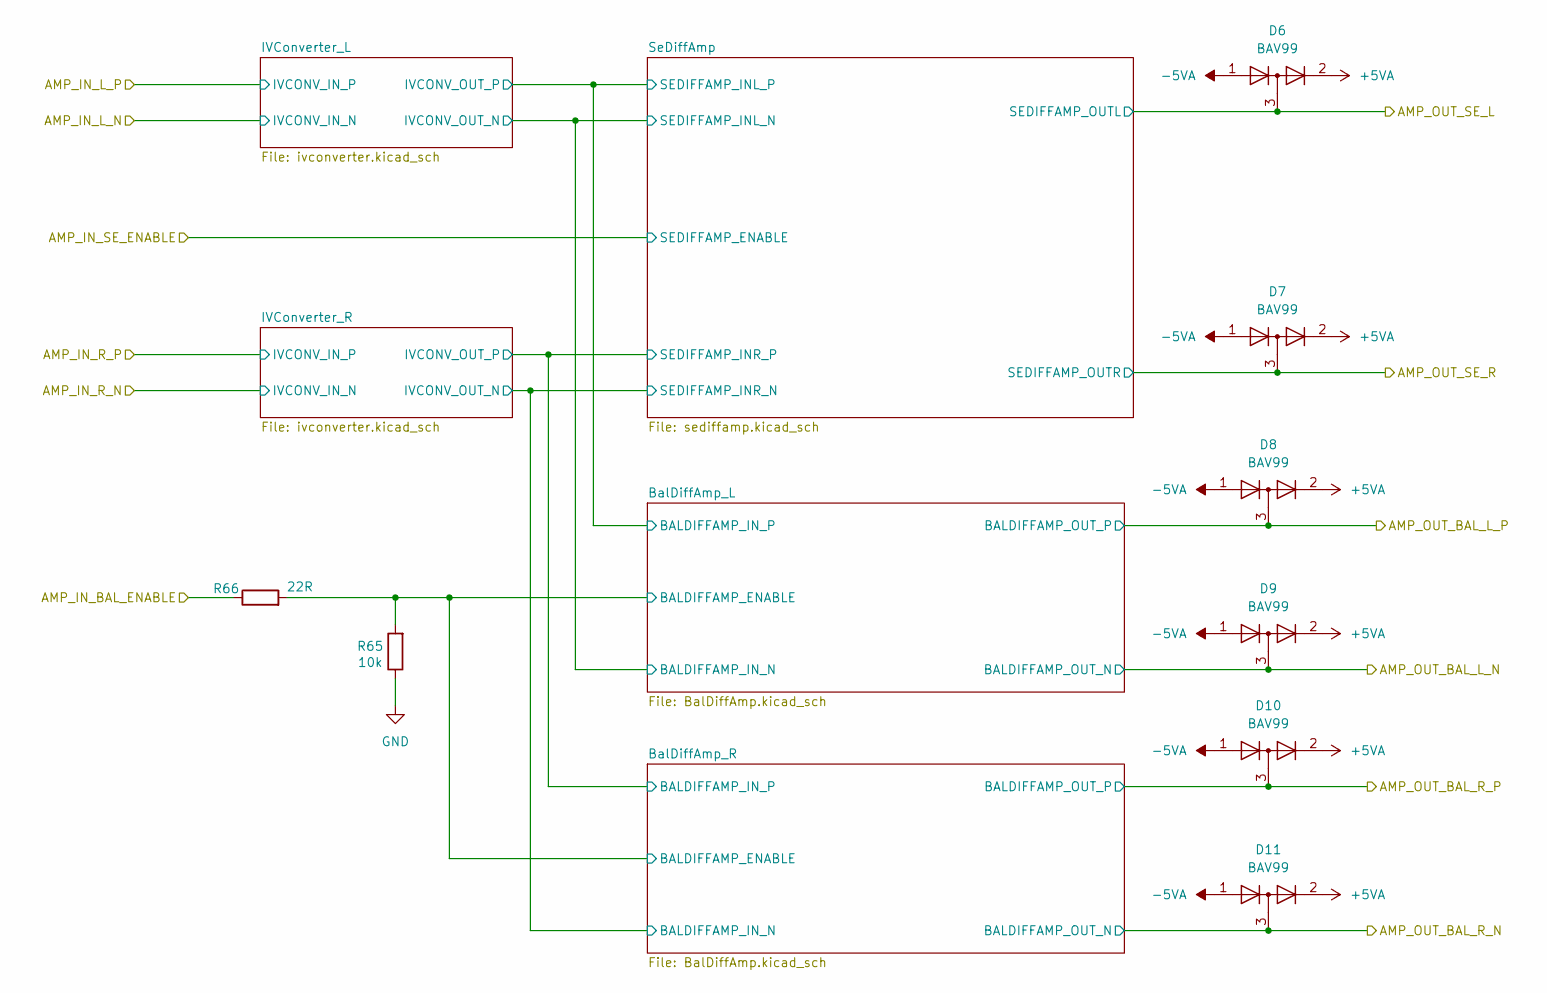
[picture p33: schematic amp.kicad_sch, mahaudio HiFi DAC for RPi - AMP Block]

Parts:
D6, D7, D8, D9, D10, D11: BAV99; SOT-23; JLCPCB Part # C2500
R65: 10k; R_0402_1005Metric_Pad0.72x0.64mm_HandSolder; Tolerance 5%; JLCPCB Part # C25744
R66: 22R; R_0402_1005Metric_Pad0.72x0.64mm_HandSolder; Tolerance 5%; JLCPCB Part # C25092

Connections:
+5VA: D6.2 (A), D7.2 (A), D8.2 (A), D9.2 (A), D10.2 (A), D11.2 (A); also elsewhere on the board
-5VA: D6.1 (K), D7.1 (K), D8.1 (K), D9.1 (K), D10.1 (K), D11.1 (K); also elsewhere on the board
/AMP/BalDiffAmp_L/BALDIFFAMP_ENABLE: R65.2, R66.2; also elsewhere on the board
/AMP_DIFF_EN: R66.1; also elsewhere on the board
/OUT_BAL_L_N: D9.3 (K); also elsewhere on the board
/OUT_BAL_L_P: D8.3 (K); also elsewhere on the board
/OUT_BAL_R_N: D11.3 (K); also elsewhere on the board
/OUT_BAL_R_P: D10.3 (K); also elsewhere on the board
/OUT_SE_L: D6.3 (K); also elsewhere on the board
/OUT_SE_R: D7.3 (K); also elsewhere on the board
GND: R65.1; also elsewhere on the board

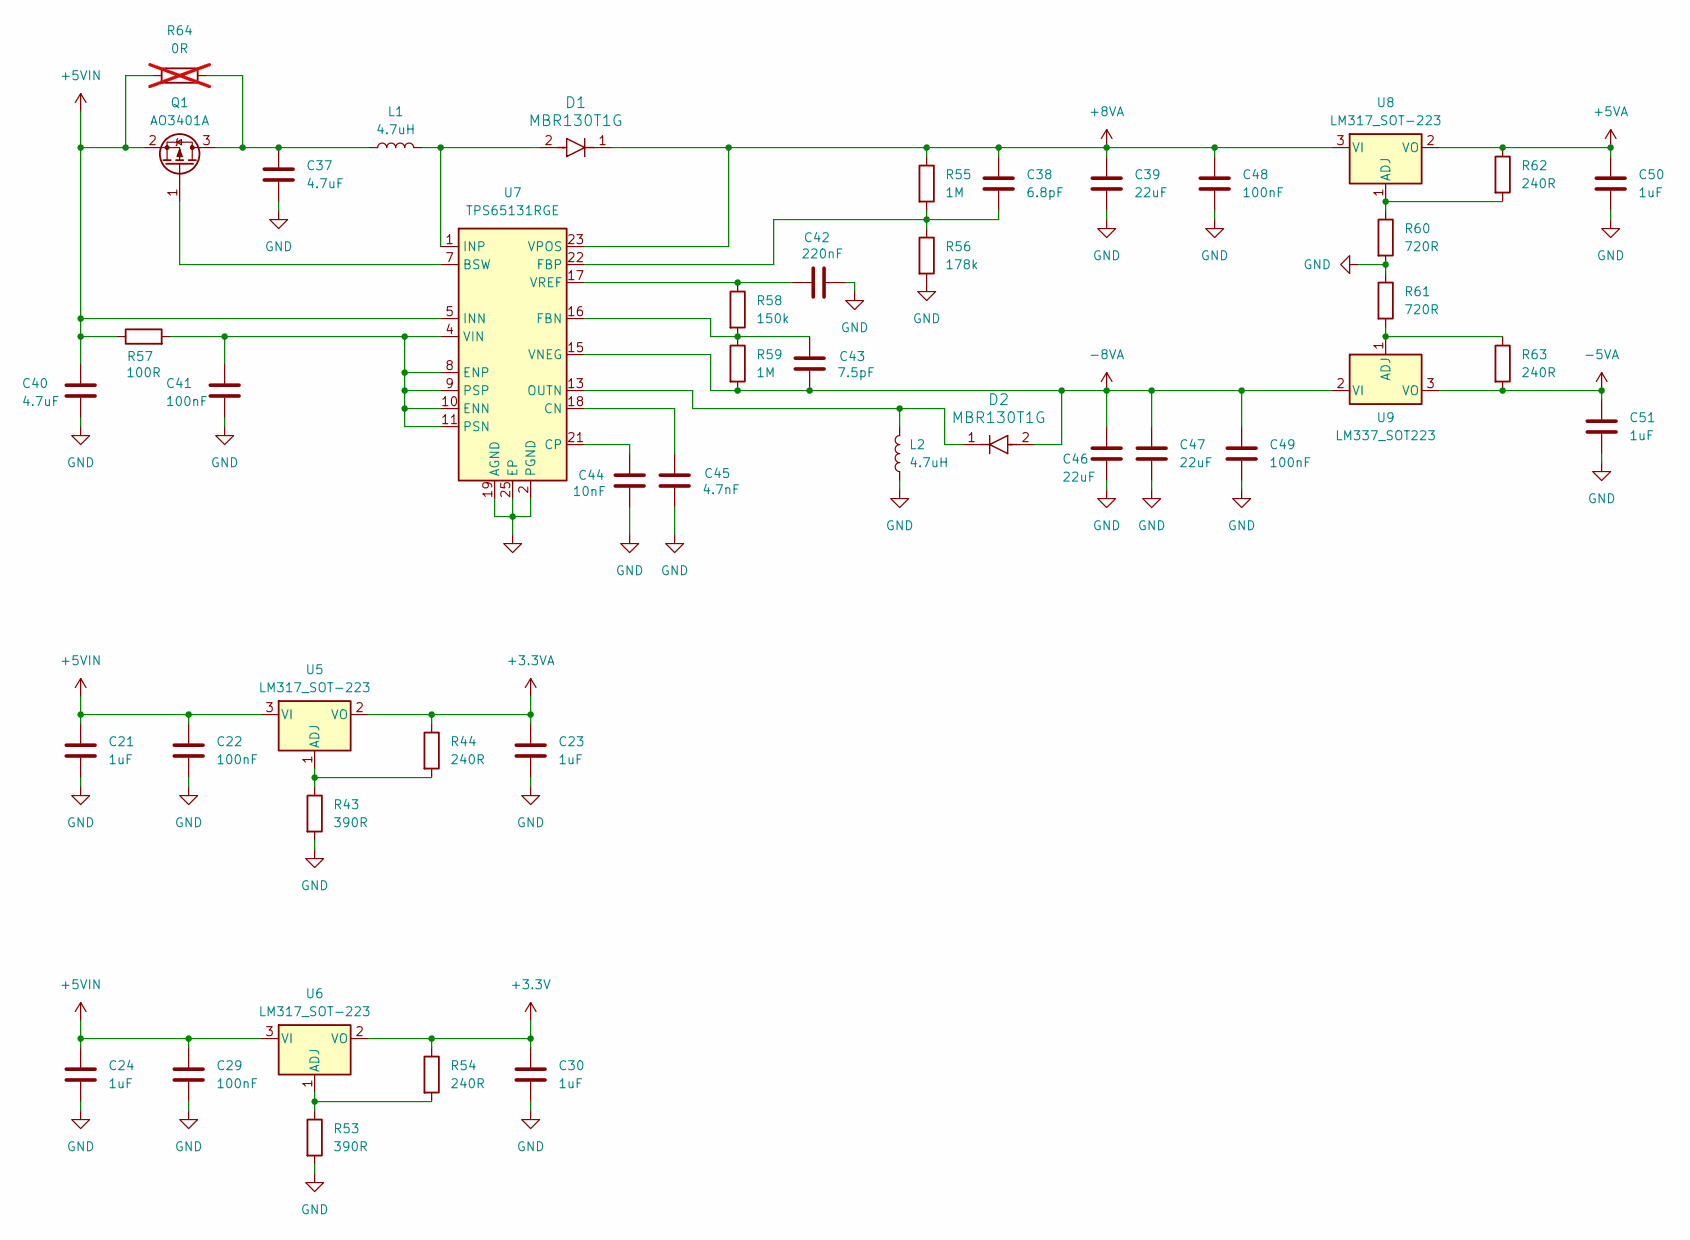
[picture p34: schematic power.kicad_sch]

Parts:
C21, C23, C24, C30, C50, C51: 1uF; C_0603_1608Metric_Pad1.08x0.95mm_HandSolder; Tolerance 10%; Voltage 16V; JLCPCB Part # C15849
C22, C29, C41, C48, C49: 100nF; C_0402_1005Metric_Pad0.74x0.62mm_HandSolder; Tolerance 10%; Voltage 16V; JLCPCB Part # C1525
C37: 4.7uF; C_0603_1608Metric_Pad1.08x0.95mm_HandSolder; Tolerance 10%; Voltage 10V; JLCPCB Part # C19666
C38: 6.8pF; C_0402_1005Metric_Pad0.74x0.62mm_HandSolder; Tolerance 0.1pF; Voltage 50V; JLCPCB Part # C88896
C39, C46, C47: 22uF; C_0603_1608Metric_Pad1.08x0.95mm_HandSolder; Tolerance 10%; Voltage 10V; JLCPCB Part # C84419
C40: 4.7uF; C_0603_1608Metric_Pad1.08x0.95mm_HandSolder; Voltage 10V; Tolerance 10%; JLCPCB Part # C19666
C42: 220nF; C_0402_1005Metric_Pad0.74x0.62mm_HandSolder; Tolerance 10%; Voltage 16V; JLCPCB Part # C16772
C43: 7.5pF; C_0402_1005Metric_Pad0.74x0.62mm_HandSolder; Tolerance 0.1pF; Voltage 50V; JLCPCB Part # C88938
C44: 10nF; C_0402_1005Metric_Pad0.74x0.62mm_HandSolder; Tolerance 10%; Voltage 50V; JLCPCB Part # C15195
C45: 4.7nF; C_0402_1005Metric_Pad0.74x0.62mm_HandSolder; Tolerance 10%; Voltage 50V; JLCPCB Part # C1538
D1, D2: MBR130T1G; SOD-123_425-04_ONS; JLCPCB Part # C82461
L1, L2: 4.7uH; WE-MAPI_4030; Tolerance 20%; Mfg Partnumber 74438357047; JLCPCB Part # C6707914
Q1: AO3401A; SOT-23; JLCPCB Part # C15127
R43, R53: 390R; R_0402_1005Metric_Pad0.72x0.64mm_HandSolder; Tolerance 1%; JLCPCB Part # C274891
R44, R54, R62, R63: 240R; R_0402_1005Metric_Pad0.72x0.64mm_HandSolder; Tolerance 1%; JLCPCB Part # C25094
R55, R59: 1M; R_0402_1005Metric_Pad0.72x0.64mm_HandSolder; Tolerance 1%; JLCPCB Part # C26083
R56: 178k; R_0402_1005Metric_Pad0.72x0.64mm_HandSolder; Tolerance 1%; JLCPCB Part # C185459
R57: 100R; R_0402_1005Metric_Pad0.72x0.64mm_HandSolder; Tolerance 5%; JLCPCB Part # C25076
R58: 150k; R_0402_1005Metric_Pad0.72x0.64mm_HandSolder; Tolerance 1%; JLCPCB Part # C25755
R60, R61: 720R; R_0402_1005Metric_Pad0.72x0.64mm_HandSolder; Tolerance 1%; JLCPCB Part # C416571
R64: 0R; R_0402_1005Metric_Pad0.72x0.64mm_HandSolder; not fitted
U5, U6, U8: LM317_SOT-223; SOT-223-3_TabPin2; JLCPCB Part # C84244
U7: TPS65131RGE; VQFN-24-1EP_4x4mm_P0.5mm_EP2.45x2.45mm_ThermalVias; JLCPCB Part # C87663
U9: LM337_SOT223; SOT-223-3_TabPin2; JLCPCB Part # C527400

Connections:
+3.3V: C30.1, R54.1, U6.2 (VO); also elsewhere on the board
+3.3VA: C23.1, R44.1, U5.2 (VO); also elsewhere on the board
+5VA: C50.1, R62.1, U8.2 (VO); also elsewhere on the board
+5VIN: C21.1, C22.1, C24.1, C29.1, C40.1, Q1.2 (S), R57.1, R64.1, U5.3 (VI), U6.3 (VI), U7.5 (INN), U7.6 (INN); also elsewhere on the board
+8VA: C38.1, C39.1, C48.1, D1.1, R55.1, U7.23 (VPOS), U8.3 (VI)
-5VA: C51.1, R63.2, U9.3 (VO); also elsewhere on the board
-8VA: C43.2, C46.1, C47.1, C49.1, D2.2, R59.2, U7.15 (VNEG), U9.2 (VI)
GND: C21.2, C22.2, C23.2, C24.2, C29.2, C30.2, C37.2, C39.2, C40.2, C41.2, C42.2, C44.2, C45.2, C46.2, C47.2, C48.2, C49.2, C50.2, C51.2, L2.1, R43.2, R53.2, R56.2, R60.2, R61.1, U7.2 (PGND), U7.3 (PGND), U7.19 (AGND), U7.25 (EP); also elsewhere on the board
unnamed: D1.2, L1.2, U7.1 (INP), U7.24 (INP)
unnamed: D2.1, L2.2, U7.13 (OUTN), U7.14 (OUTN)
unnamed: C37.1, L1.1, Q1.3 (D), R64.2
unnamed: Q1.1 (G), U7.7 (BSW)
unnamed: R43.1, R44.2, U5.1 (ADJ)
unnamed: R53.1, R54.2, U6.1 (ADJ)
unnamed: C45.1, U7.18 (CN)
unnamed: C44.1, U7.21 (CP)
unnamed: C41.1, R57.2, U7.4 (VIN), U7.8 (ENP), U7.9 (PSP), U7.10 (ENN), U7.11 (PSN)
unnamed: C43.1, R58.2, R59.1, U7.16 (FBN)
unnamed: C38.2, R55.2, R56.1, U7.22 (FBP)
unnamed: C42.1, R58.1, U7.17 (VREF)
unnamed: R60.1, R62.2, U8.1 (ADJ)
unnamed: R61.2, R63.1, U9.1 (ADJ)

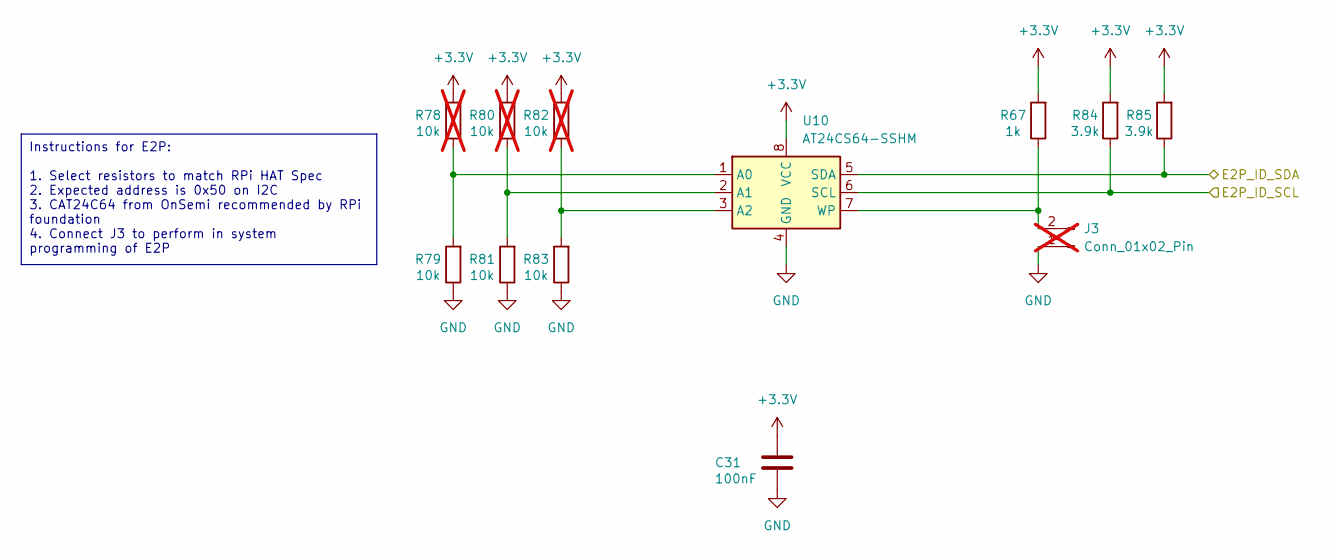
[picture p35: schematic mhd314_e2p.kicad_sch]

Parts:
C31: 100nF; C_0402_1005Metric_Pad0.74x0.62mm_HandSolder; Tolerance 10%; Voltage 16V; JLCPCB Part # C1525
J3: Conn_01x02_Pin; PinHeader_1x02_P1.00mm_Vertical; not fitted
R67: 1k; R_0402_1005Metric_Pad0.72x0.64mm_HandSolder; Tolerance 5%; JLCPCB Part # C11702
R78, R80, R82: 10k; R_0402_1005Metric_Pad0.72x0.64mm_HandSolder; Tolerance 5%; not fitted
R79, R81, R83: 10k; R_0402_1005Metric_Pad0.72x0.64mm_HandSolder; Tolerance 5%; JLCPCB Part # C25744
R84, R85: 3.9k; R_0402_1005Metric_Pad0.72x0.64mm_HandSolder; Tolerance 5%; JLCPCB Part # C51721
U10: AT24CS64-SSHM; SOIC-8_3.9x4.9mm_P1.27mm; JLCPCB Part # C81193

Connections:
+3.3V: C31.1, R67.2, R78.2, R80.2, R82.2, R84.2, R85.2, U10.8 (VCC); also elsewhere on the board
/BRD_ID_SC: R84.1, U10.6 (SCL); also elsewhere on the board
/BRD_ID_SD: R85.1, U10.5 (SDA); also elsewhere on the board
GND: C31.2, J3.1, R79.1, R81.1, R83.1, U10.4 (GND); also elsewhere on the board
unnamed: J3.2, R67.1, U10.7 (WP)
unnamed: R78.1, R79.2, U10.1 (A0)
unnamed: R80.1, R81.2, U10.2 (A1)
unnamed: R82.1, R83.2, U10.3 (A2)

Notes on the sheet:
Instructions for E2P: 1. Select resistors to match RPi HAT Spec 2. Expected address is 0x50 on I2C 3. CAT24C64 from OnSemi recommended by RPi foundation 4. Connect J3 to perform in system programming of E2P

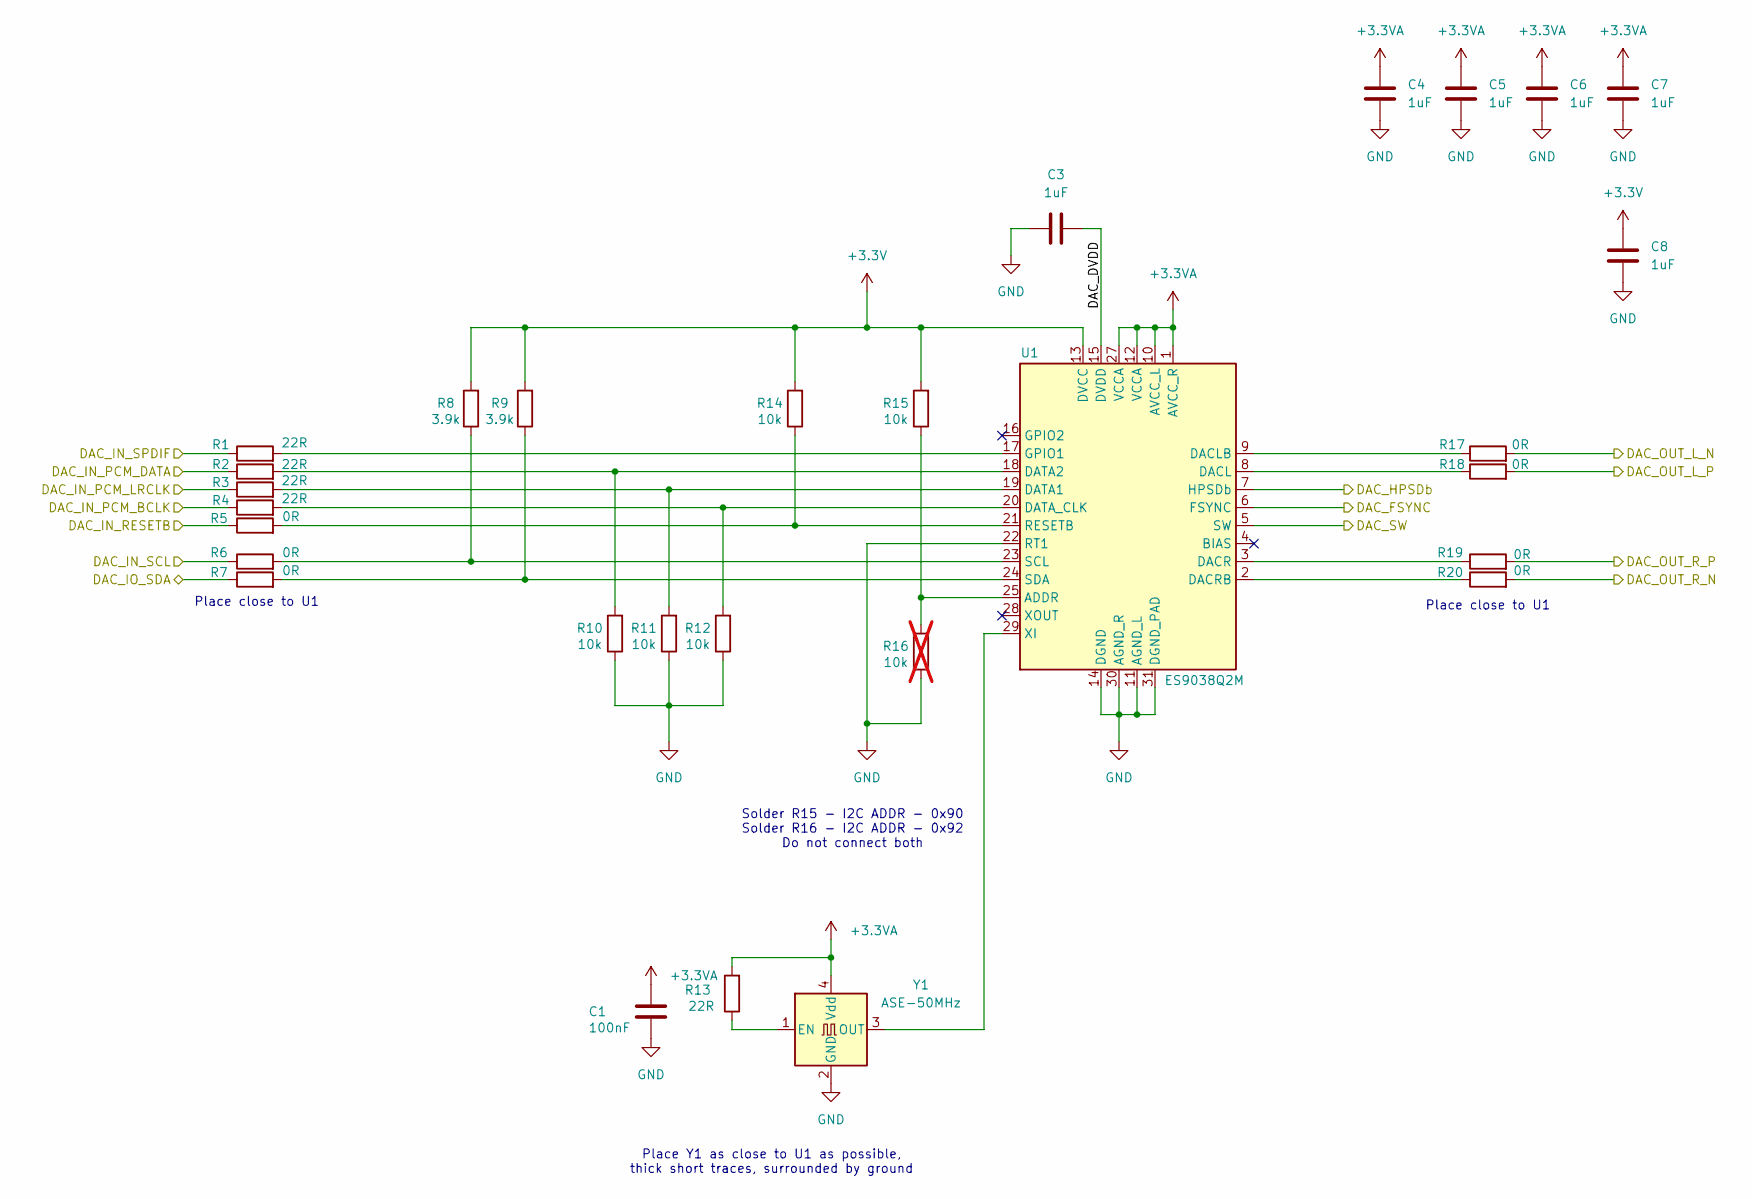
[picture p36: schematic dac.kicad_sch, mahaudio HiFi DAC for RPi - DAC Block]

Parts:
C1: 100nF; C_0402_1005Metric_Pad0.74x0.62mm_HandSolder; Tolerance 10%; Voltage 16V; JLCPCB Part # C1525
C3, C4, C5, C6, C7, C8: 1uF; C_0603_1608Metric_Pad1.08x0.95mm_HandSolder; Tolerance 10%; Voltage 16V; JLCPCB Part # C15849
R1, R2, R3, R4, R13: 22R; R_0402_1005Metric_Pad0.72x0.64mm_HandSolder; Tolerance 5%; JLCPCB Part # C25092
R5, R6, R7, R17, R18, R19, R20: 0R; R_0402_1005Metric_Pad0.72x0.64mm_HandSolder; JLCPCB Part # C17168
R8, R9: 3.9k; R_0402_1005Metric_Pad0.72x0.64mm_HandSolder; Tolerance 5%; JLCPCB Part # C51721
R10, R11, R12, R14, R15: 10k; R_0402_1005Metric_Pad0.72x0.64mm_HandSolder; Tolerance 5%; JLCPCB Part # C25744
R16: 10k; R_0402_1005Metric_Pad0.72x0.64mm_HandSolder; Tolerance 5%; not fitted
U1: ES9038Q2M; QFN-30_EP_3x5_Pitch0.4mm; JLCPCB Part # C2682306
Y1: ASE-50MHz; Oscillator_SMD_Abracon_ASE-4Pin_3.2x2.5mm; JLCPCB Part # C19725350

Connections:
+3.3V: C8.1, R8.2, R9.2, R14.2, R15.2, U1.13 (DVCC); also elsewhere on the board
+3.3VA: C1.1, C4.1, C5.1, C6.1, C7.1, R13.2, U1.1 (AVCC_R), U1.10 (AVCC_L), U1.12 (VCCA), U1.27 (VCCA), Y1.4 (Vdd); also elsewhere on the board
/BRD_ONOFF: R6.1; also elsewhere on the board
/DAC/DAC_DVDD: C3.2, U1.15 (DVDD)
/DAC/DAC_FSYNC: U1.6 (FSYNC)
/DAC/DAC_HPSDb: U1.7 (HPSDb)
/DAC/DAC_SW: U1.5 (SW)
/DAC_OUT_L_N: R17.2; also elsewhere on the board
/DAC_OUT_L_P: R18.2; also elsewhere on the board
/DAC_OUT_R_N: R20.2; also elsewhere on the board
/DAC_OUT_R_P: R19.2; also elsewhere on the board
/DAC_PCM_CLK: R4.1; also elsewhere on the board
/DAC_PCM_DATA: R2.1; also elsewhere on the board
/DAC_PCM_FS: R3.1; also elsewhere on the board
/DAC_RESETB: R5.1; also elsewhere on the board
/DAC_SDA: R7.1; also elsewhere on the board
/DAC_SPDIF: R1.1; also elsewhere on the board
GND: C1.2, C3.1, C4.2, C5.2, C6.2, C7.2, C8.2, R10.1, R11.1, R12.1, R16.1, U1.11 (AGND_L), U1.14 (DGND), U1.22 (RT1), U1.30 (AGND_R), U1.31 (DGND_PAD), Y1.2 (GND); also elsewhere on the board
unnamed: R15.1, R16.2, U1.25 (ADDR)
unnamed: R18.1, U1.8 (DACL)
unnamed: R17.1, U1.9 (DACLB)
unnamed: R19.1, U1.3 (DACR)
unnamed: R20.1, U1.2 (DACRB)
unnamed: R3.2, R11.2, U1.19 (DATA1)
unnamed: R2.2, R10.2, U1.18 (DATA2)
unnamed: R4.2, R12.2, U1.20 (DATA_CLK)
unnamed: R1.2, U1.17 (GPIO1)
unnamed: R5.2, R14.1, U1.21 (RESETB)
unnamed: R6.2, R8.1, U1.23 (SCL)
unnamed: R7.2, R9.1, U1.24 (SDA)
unnamed: U1.29 (XI), Y1.3 (OUT)
unnamed: R13.1, Y1.1 (EN)

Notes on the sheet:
Place close to U1
Solder R15 - I2C ADDR - 0x90 Solder R16 - I2C ADDR - 0x92 Do not connect both
Place Y1 as close to U1 as possible, thick short traces, surrounded by ground

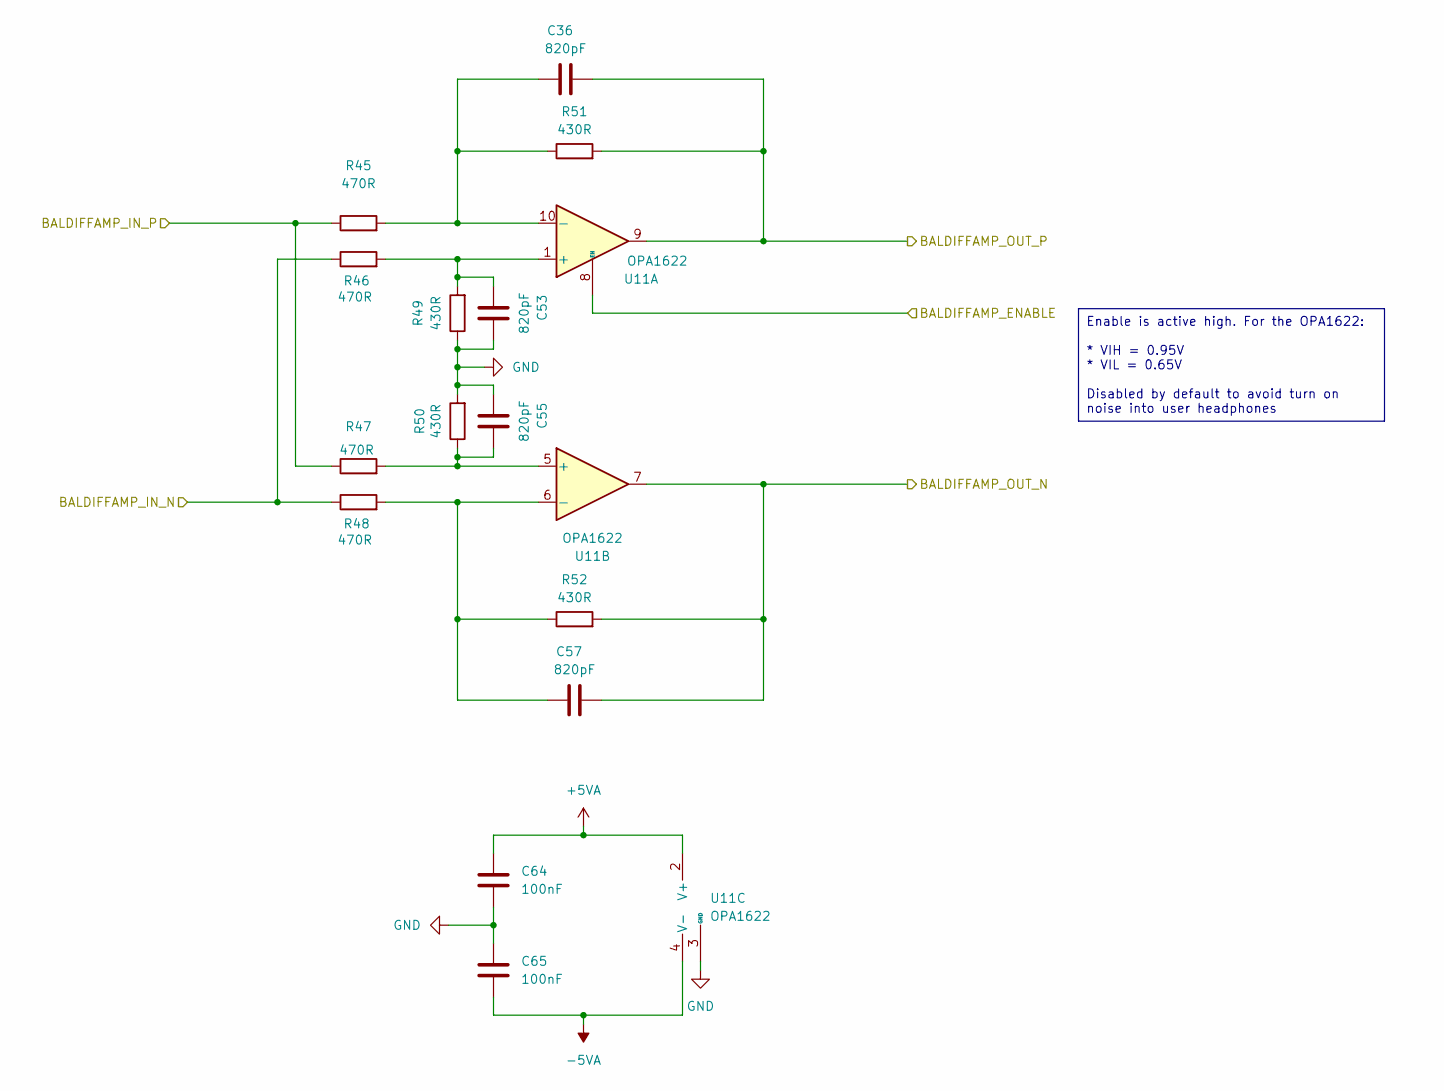
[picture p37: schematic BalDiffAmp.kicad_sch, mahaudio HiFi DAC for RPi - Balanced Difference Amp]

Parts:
C36, C53, C55, C57: 820pF; C_0603_1608Metric_Pad1.08x0.95mm_HandSolder; Tolerance 10%; Voltage 50V; JLCPCB Part # C99081
C64, C65: 100nF; C_0402_1005Metric_Pad0.74x0.62mm_HandSolder; Tolerance 10%; Voltage 16V; JLCPCB Part # C1525
R45, R46, R47, R48: 470R; R_0402_1005Metric_Pad0.72x0.64mm_HandSolder; Tolerance 0.1%; JLCPCB Part # C445590
R49, R50, R51, R52: 430R; R_0402_1005Metric_Pad0.72x0.64mm_HandSolder; Tolerance 0.1%; JLCPCB Part # C186317
U11: OPA1622; Texas_S-PVSON-N10; JLCPCB Part # C2876559

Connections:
+5VA: C64.1, U11.2 (V+); also elsewhere on the board
-5VA: C65.2, U11.4 (V-), U11.11 (V-); also elsewhere on the board
/AMP/BalDiffAmp_L/BALDIFFAMP_ENABLE: U11.8 (EN); also elsewhere on the board
/AMP/BalDiffAmp_L/BALDIFFAMP_IN_N: R46.1, R48.1; also elsewhere on the board
/AMP/BalDiffAmp_L/BALDIFFAMP_IN_P: R45.1, R47.1; also elsewhere on the board
/OUT_BAL_L_N: C57.2, R52.2, U11.7; also elsewhere on the board
/OUT_BAL_L_P: C36.2, R51.2, U11.9; also elsewhere on the board
GND: C53.2, C55.1, C64.2, C65.1, R49.1, R50.2, U11.3 (GND); also elsewhere on the board
unnamed: C53.1, R46.2, R49.2, U11.1 (+)
unnamed: C36.1, R45.2, R51.1, U11.10 (-)
unnamed: C55.2, R47.2, R50.1, U11.5 (+)
unnamed: C57.1, R48.2, R52.1, U11.6 (-)

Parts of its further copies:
C35, C52, C54, C56: 820pF; C_0603_1608Metric_Pad1.08x0.95mm_HandSolder; Tolerance 10%; Voltage 50V; JLCPCB Part # C99081
C60, C61: 100nF; C_0402_1005Metric_Pad0.74x0.62mm_HandSolder; Tolerance 10%; Voltage 16V; JLCPCB Part # C1525
R35, R36, R39, R40: 470R; R_0402_1005Metric_Pad0.72x0.64mm_HandSolder; Tolerance 0.1%; JLCPCB Part # C445590
R37, R38, R41, R42: 430R; R_0402_1005Metric_Pad0.72x0.64mm_HandSolder; Tolerance 0.1%; JLCPCB Part # C186317
U4: OPA1622; Texas_S-PVSON-N10; JLCPCB Part # C2876559

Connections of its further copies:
+5VA: C60.1, U4.2 (V+); also elsewhere on the board
-5VA: C61.2, U4.4 (V-), U4.11 (V-); also elsewhere on the board
/AMP/BalDiffAmp_L/BALDIFFAMP_ENABLE: U4.8 (EN); also elsewhere on the board
/AMP/BalDiffAmp_R/BALDIFFAMP_IN_N: R36.1, R40.1; also elsewhere on the board
/AMP/BalDiffAmp_R/BALDIFFAMP_IN_P: R35.1, R39.1; also elsewhere on the board
/OUT_BAL_R_N: C56.2, R42.2, U4.7; also elsewhere on the board
/OUT_BAL_R_P: C35.2, R37.2, U4.9; also elsewhere on the board
GND: C52.2, C54.1, C60.2, C61.1, R38.1, R41.2, U4.3 (GND); also elsewhere on the board
unnamed: C52.1, R36.2, R38.2, U4.1 (+)
unnamed: C35.1, R35.2, R37.1, U4.10 (-)
unnamed: C54.2, R39.2, R41.1, U4.5 (+)
unnamed: C56.1, R40.2, R42.1, U4.6 (-)

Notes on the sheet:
Enable is active high. For the OPA1622: * VIH = 0.95V * VIL = 0.65V Disabled by default to avoid turn on noise into user headphones

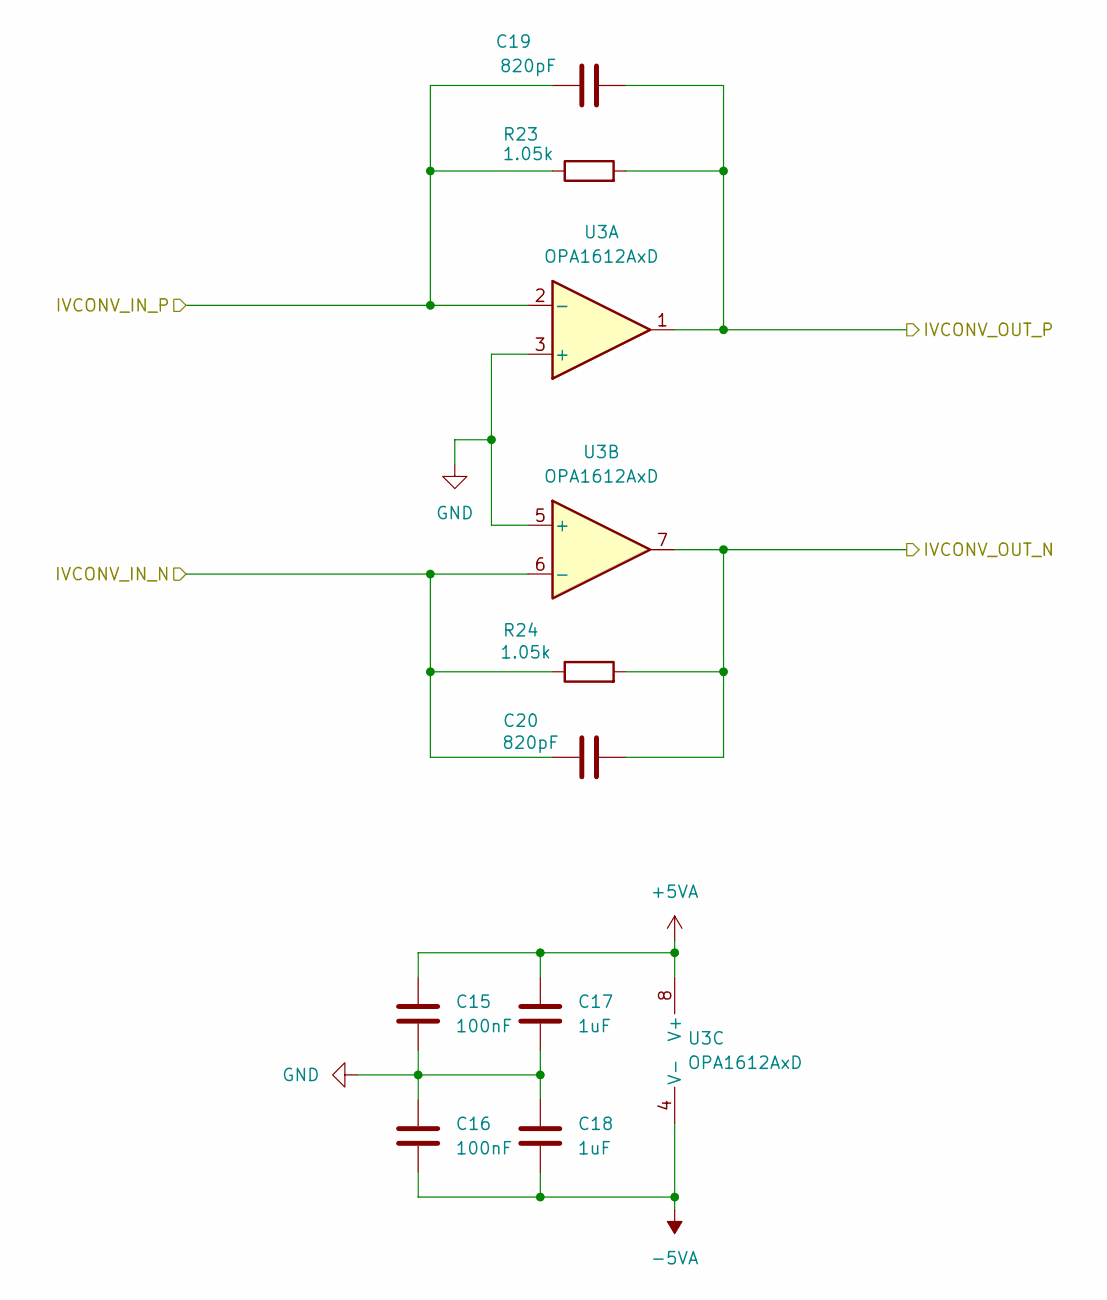
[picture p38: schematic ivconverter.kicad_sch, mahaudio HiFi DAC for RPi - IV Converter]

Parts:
C15, C16: 100nF; C_0402_1005Metric_Pad0.74x0.62mm_HandSolder; Tolerance 10%; Voltage 16V; JLCPCB Part # C1525
C17, C18: 1uF; C_0603_1608Metric_Pad1.08x0.95mm_HandSolder; Tolerance 10%; Voltage 16V; JLCPCB Part # C15849
C19, C20: 820pF; C_0603_1608Metric_Pad1.08x0.95mm_HandSolder; Tolerance 10%; Voltage 50V; JLCPCB Part # C99081
R23, R24: 1.05k; R_0402_1005Metric_Pad0.72x0.64mm_HandSolder; Tolerance 0.1%; JLCPCB Part # C2693047
U3: OPA1612AxD; SOIC-8_3.9x4.9mm_P1.27mm; JLCPCB Part # C94590

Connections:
+5VA: C15.1, C17.1, U3.8 (V+); also elsewhere on the board
-5VA: C16.2, C18.2, U3.4 (V-); also elsewhere on the board
/AMP/BalDiffAmp_R/BALDIFFAMP_IN_N: C20.2, R24.2, U3.7; also elsewhere on the board
/AMP/BalDiffAmp_R/BALDIFFAMP_IN_P: C19.2, R23.2, U3.1; also elsewhere on the board
/DAC_OUT_R_N: C20.1, R24.1, U3.6 (-); also elsewhere on the board
/DAC_OUT_R_P: C19.1, R23.1, U3.2 (-); also elsewhere on the board
GND: C15.2, C16.1, C17.2, C18.1, U3.3 (+), U3.5 (+); also elsewhere on the board

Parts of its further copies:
C9, C10: 100nF; C_0402_1005Metric_Pad0.74x0.62mm_HandSolder; Tolerance 10%; Voltage 16V; JLCPCB Part # C1525
C11, C12: 1uF; C_0603_1608Metric_Pad1.08x0.95mm_HandSolder; Tolerance 10%; Voltage 16V; JLCPCB Part # C15849
C13, C14: 820pF; C_0603_1608Metric_Pad1.08x0.95mm_HandSolder; Tolerance 10%; Voltage 50V; JLCPCB Part # C99081
R21, R22: 1.05k; R_0402_1005Metric_Pad0.72x0.64mm_HandSolder; Tolerance 0.1%; JLCPCB Part # C2693047
U2: OPA1612AxD; SOIC-8_3.9x4.9mm_P1.27mm; JLCPCB Part # C94590

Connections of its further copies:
+5VA: C9.1, C11.1, U2.8 (V+); also elsewhere on the board
-5VA: C10.2, C12.2, U2.4 (V-); also elsewhere on the board
/AMP/BalDiffAmp_L/BALDIFFAMP_IN_N: C14.2, R22.2, U2.7; also elsewhere on the board
/AMP/BalDiffAmp_L/BALDIFFAMP_IN_P: C13.2, R21.2, U2.1; also elsewhere on the board
/DAC_OUT_L_N: C14.1, R22.1, U2.6 (-); also elsewhere on the board
/DAC_OUT_L_P: C13.1, R21.1, U2.2 (-); also elsewhere on the board
GND: C9.2, C10.1, C11.2, C12.1, U2.3 (+), U2.5 (+); also elsewhere on the board

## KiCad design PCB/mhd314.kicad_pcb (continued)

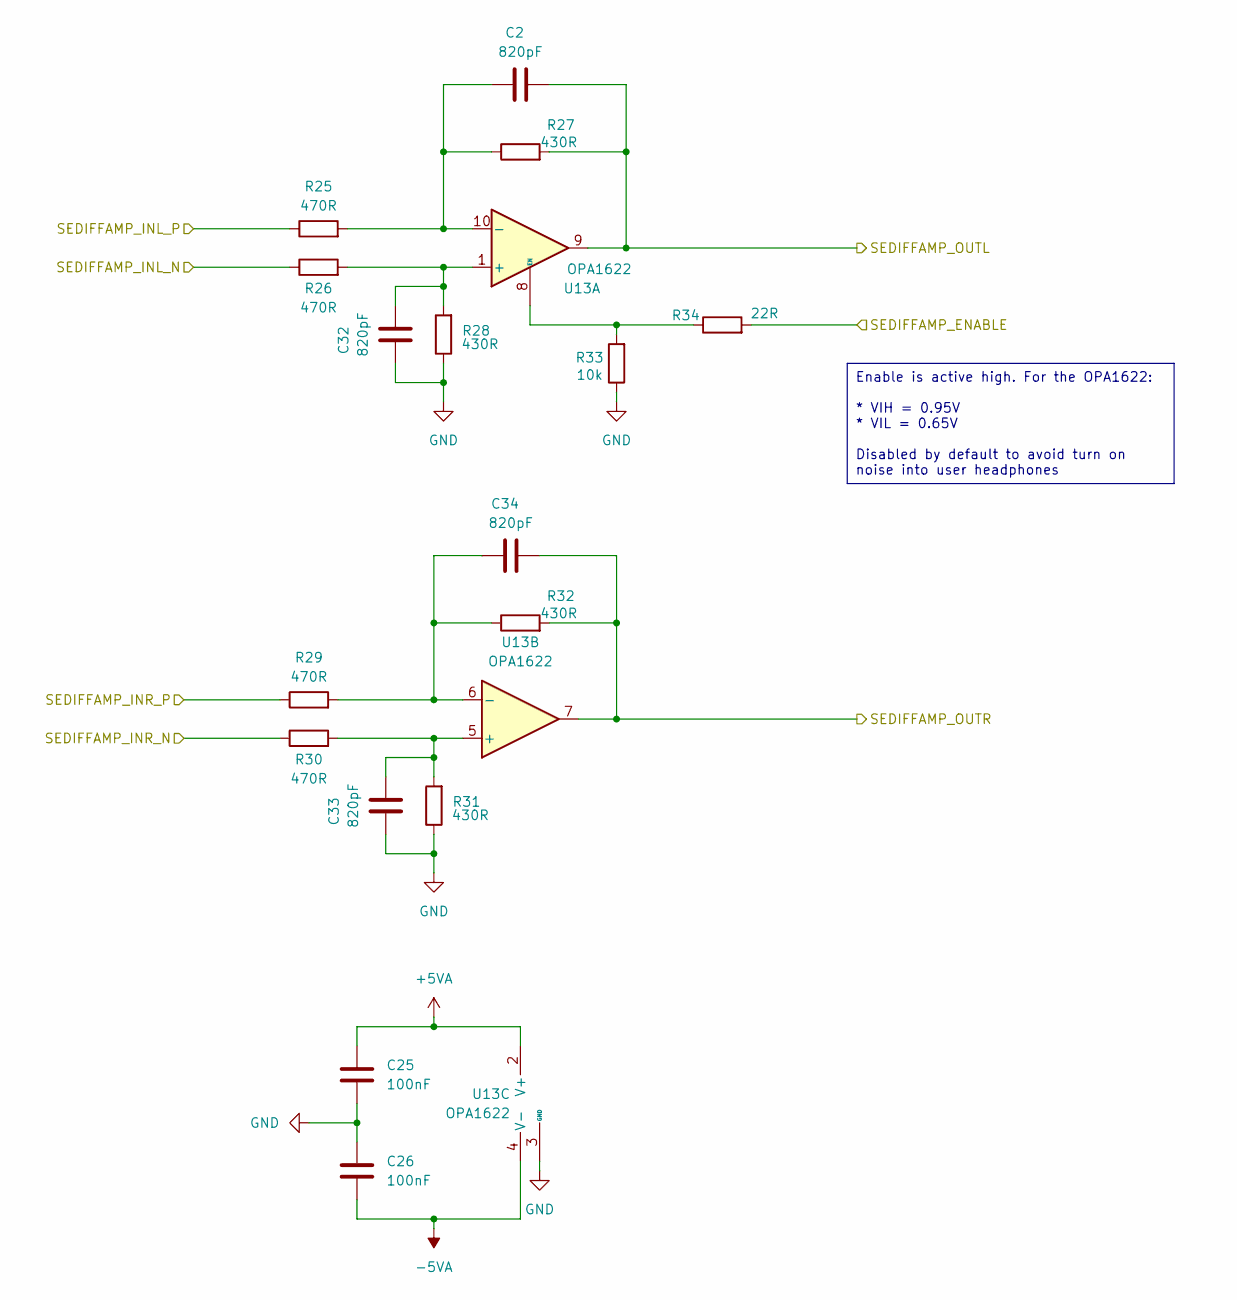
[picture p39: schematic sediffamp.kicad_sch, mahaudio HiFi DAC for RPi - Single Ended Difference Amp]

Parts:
C2, C32, C33, C34: 820pF; C_0603_1608Metric_Pad1.08x0.95mm_HandSolder; Tolerance 10%; Voltage 50V; JLCPCB Part # C99081
C25, C26: 100nF; C_0402_1005Metric_Pad0.74x0.62mm_HandSolder; Tolerance 10%; Voltage 16V; JLCPCB Part # C1525
R25, R26, R29, R30: 470R; R_0402_1005Metric_Pad0.72x0.64mm_HandSolder; Tolerance 0.1%; JLCPCB Part # C445590
R27, R28, R31, R32: 430R; R_0402_1005Metric_Pad0.72x0.64mm_HandSolder; Tolerance 0.1%; JLCPCB Part # C186317
R33: 10k; R_0402_1005Metric_Pad0.72x0.64mm_HandSolder; Tolerance 5%; JLCPCB Part # C25744
R34: 22R; R_0402_1005Metric_Pad0.72x0.64mm_HandSolder; Tolerance 5%; JLCPCB Part # C25092
U13: OPA1622; Texas_S-PVSON-N10; JLCPCB Part # C2876559

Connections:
+5VA: C25.1, U13.2 (V+); also elsewhere on the board
-5VA: C26.2, U13.4 (V-), U13.11 (V-); also elsewhere on the board
/AMP/BalDiffAmp_L/BALDIFFAMP_IN_N: R26.1; also elsewhere on the board
/AMP/BalDiffAmp_L/BALDIFFAMP_IN_P: R25.1; also elsewhere on the board
/AMP/BalDiffAmp_R/BALDIFFAMP_IN_N: R30.1; also elsewhere on the board
/AMP/BalDiffAmp_R/BALDIFFAMP_IN_P: R29.1; also elsewhere on the board
/AMP_SE_EN: R34.2; also elsewhere on the board
/OUT_SE_L: C2.2, R27.2, U13.9; also elsewhere on the board
/OUT_SE_R: C34.2, R32.2, U13.7; also elsewhere on the board
GND: C25.2, C26.1, C32.1, C33.1, R28.1, R31.1, R33.1, U13.3 (GND); also elsewhere on the board
unnamed: C32.2, R26.2, R28.2, U13.1 (+)
unnamed: C2.1, R25.2, R27.1, U13.10 (-)
unnamed: R33.2, R34.1, U13.8 (EN)
unnamed: C33.2, R30.2, R31.2, U13.5 (+)
unnamed: C34.1, R29.2, R32.1, U13.6 (-)

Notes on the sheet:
Enable is active high. For the OPA1622: * VIH = 0.95V * VIL = 0.65V Disabled by default to avoid turn on noise into user headphones

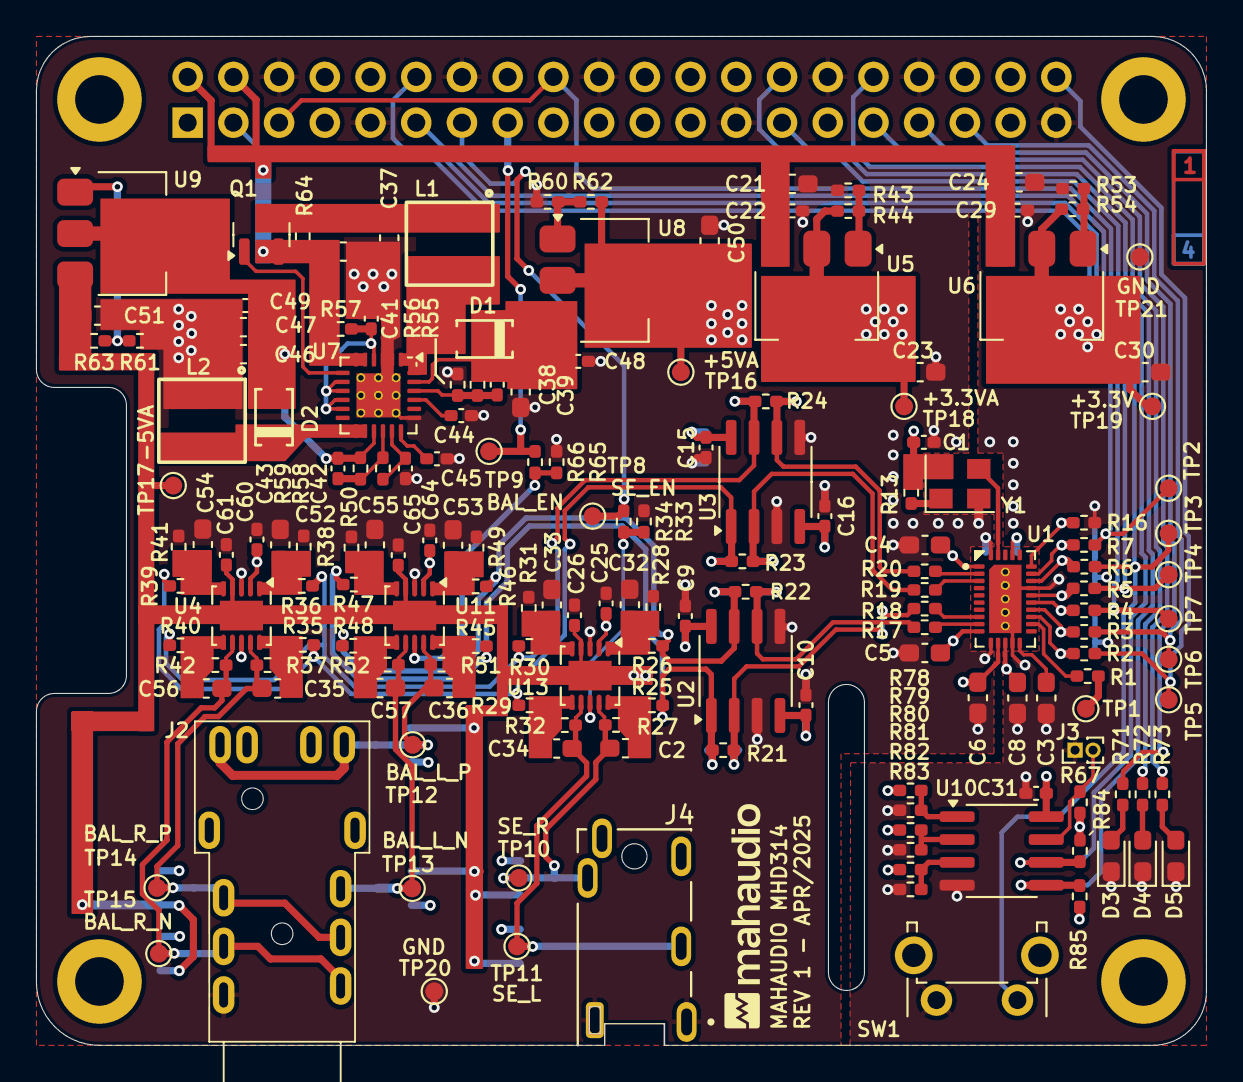
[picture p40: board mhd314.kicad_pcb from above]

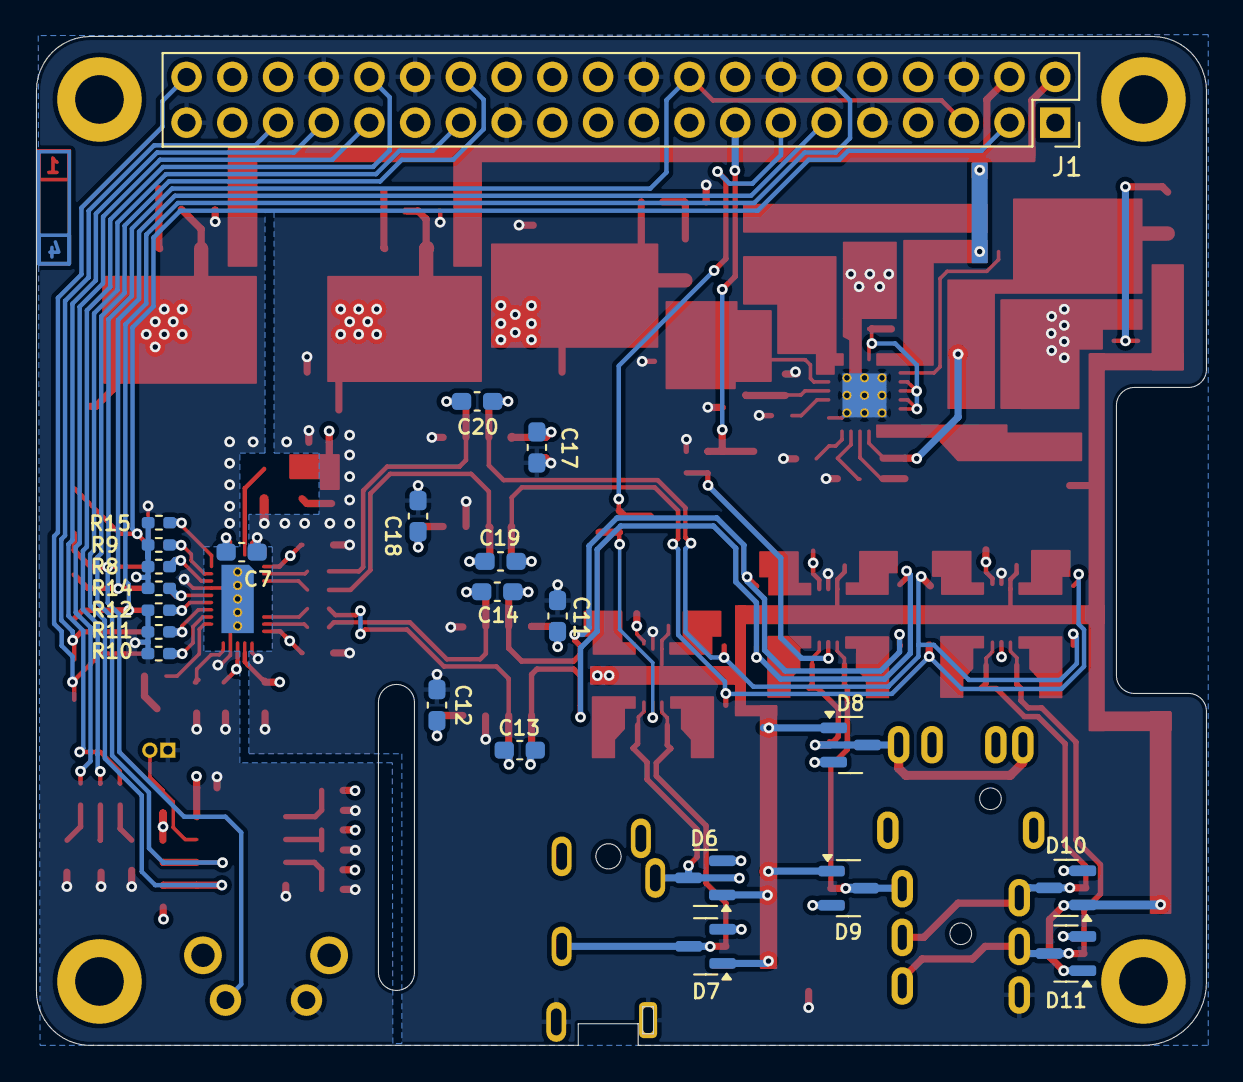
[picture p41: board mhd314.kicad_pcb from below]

Board: 4 copper layers, 65.0 x 56.1 mm, 194 parts (23 on the bottom side), 86 nets.

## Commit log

2024-08-15 Added PCB project with DAC module
    [mhd314.kicad_pcb, mhd314.kicad_sch]
2024-08-28 Finalized DAC and made it a module. Added Live 09 presentation
    [dac.kicad_sch, mhd314.kicad_sch]
2024-09-04 Updated dac schematics and added simulations. Updated until Live 11
    [dac.kicad_sch]
2024-09-19 Added AMP stage circuits. Updated until Live 13
    [BalDiffAmp.kicad_sch, amp.kicad_sch, ivconverter.kicad_sch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]
2024-10-31 Added power supply and adjusted the AMP section to use only OPA1622 as output amp. In sync with Live 16
    [BalDiffAmp.kicad_sch, amp.kicad_sch, dac.kicad_sch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]
2024-10-31 Added WE inductor for power. Library is attached to project for reference
    [power.kicad_sch]
2024-12-04 Added connectors
    [mhd314.kicad_sch]
2024-12-16 Added E2P and testpoints
    [BalDiffAmp.kicad_sch, amp.kicad_sch, dac.kicad_sch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]
2024-12-19 PCB drawn with connector placement ok
    [mhd314.kicad_pcb, mhd314.kicad_sch]
2025-01-09 Started placement, current with Live 20
    [mhd314.kicad_pcb]
2025-01-22 Finished basic placement
    [BalDiffAmp.kicad_sch, dac.kicad_sch, mhd314.kicad_pcb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]
2025-02-05 Routed power section
    [BalDiffAmp.kicad_sch, amp.kicad_sch, dac.kicad_sch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]
2025-02-07 Routed DAC section
    [dac.kicad_sch, mhd314.kicad_pcb]
2025-02-21 Routed single ended path and moved some components to top side
    [mhd314.kicad_pcb]
2025-02-25 Advances all basic track routing. Pending power planes, grounding and optimization
    [dac.kicad_sch, mhd314.kicad_pcb]
2025-02-27 Basic routing finished. Still missing some optimizing steps and DRC
    [ASE-50.000MHZ-LC-T.STEP, MBR130T1G.step, SJ1-3535NG-GR.step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]
2025-03-05 Routing revised, added some missing parameters to components
    [BalDiffAmp.kicad_sch, dac.kicad_sch, ivconverter.kicad_sch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]
2025-03-06 Updated PCB with digital traxce suggestions. Added JLCPCB Pns
    [BalDiffAmp.kicad_sch, amp.kicad_sch, dac.kicad_sch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]
2025-03-06 Updates some DNPs on PCB
    [mhd314.kicad_pcb]
2025-03-08 Changed the 4.4mm connector and fixed a bunch o library related problems
    [mhd314.kicad_pcb, mhd314.kicad_sch]
2025-03-12 Increased trace width and clearance to 0.15mm. Changed the Pentaconn connector to JLCPCB supported part from GSwitch
    [mhd314.kicad_pcb]
2025-03-13 Changed resistor values to match JLCPCB + general board revision
    [BalDiffAmp.kicad_sch, ivconverter.kicad_sch, mhd314.kicad_pcb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]
2025-03-17 Added filter capacitors to OPA1622 circuitry
    [BalDiffAmp.kicad_sch, amp.kicad_sch, dac.kicad_sch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]
2025-03-17 Improved silk screen positioning and optimized some of the tracks
    [mhd314.kicad_pcb]
2025-03-18 Optimized designator positions and DNP for capacitors in OPA1622
    [BalDiffAmp.kicad_sch, mhd314.kicad_pcb, mhd314.kicad_sch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]
2025-03-18 Redone placement and layout of OPA1622. Still finishing touches
    [BalDiffAmp.kicad_sch, amp.kicad_sch, mhd314.kicad_pcb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]
2025-03-19 Finished routing with new OPA1622 layout. Pending review of designators.
    [mhd314.kicad_pcb]
2025-03-19 Optimized tracks and designators
    [mhd314.kicad_pcb]
2025-03-19 Changed the BOM field for JLCPCB to the original name instead of LCSC
    [BalDiffAmp.kicad_sch, amp.kicad_sch, dac.kicad_sch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]
2025-03-20 Changed single ended connector for gold plated part and changed resistor and capacitor values of opa1622 amp for improved power on high impedance headphones
    [BalDiffAmp.kicad_sch, ivconverter.kicad_sch, mhd314.kicad_pcb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]
2025-04-15 Changes in E2P for better identification of the board
    [dac.kicad_sch, mhd314.kicad_pcb, mhd314.kicad_sch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]
2025-04-16 Updated inductor to improve production
    [mhd314.kicad_pcb]
2025-04-16 Added courtyard information on Inductor
    [mhd314.kicad_pcb]
